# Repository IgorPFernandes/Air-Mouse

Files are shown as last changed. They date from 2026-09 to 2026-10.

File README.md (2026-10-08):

# Air Mouse

Mouse controlado por movimento da mão, feito com ESP32-C3 e MPU6050.

O aparelho se apresenta ao computador como um **mouse Bluetooth LE padrão (HID)**:
sem driver, sem dongle, sem software do lado do host. Funciona com Windows,
macOS, Linux, Android e iPadOS.

---

## Características

- **HID BLE nativo**, implementado direto sobre o NimBLE — sem biblioteca HID de
  terceiros.
- **Compensação de rotação do pulso** por filtro complementar: os eixos da tela
  continuam corretos mesmo com o aparelho inclinado de lado.
- **Curva de aceleração** com termo linear e quadrático: precisão no movimento
  fino, alcance no movimento rápido.
- **Acumulador de sub-pixel**, para que gestos lentos não sejam truncados a zero.
- **Calibração validada no boot** — a medição é rejeitada se o aparelho estiver
  sendo movido.
- **Modo scroll** com o botão do meio segurado.
- **Nível de bateria** reportado ao sistema operacional.
- **Gestão de energia em três estados** — ativo (~22 mA), ocioso com a conexão
  mantida (~1,9 mA) e sono profundo (~84 µA). Com duas 18650 em paralelo, cerca
  de **6,7 semanas** entre cargas numa jornada de 8 h com o aparelho na mão; ver
  [Autonomia](#autonomia).
- **Despertar por movimento**: pegar o aparelho já o acorda, sem apertar nada.
- **Botão de centralizar**, para reencontrar o cursor quando se perde de vista.
- **Três níveis de velocidade** com confirmação por LED RGB.

---

## Estrutura

```
├── include/
│   └── config.h              parâmetros de hardware e ajuste
├── src/
│   ├── main.cpp              inicialização e laço principal
│   ├── mpu6050.{h,cpp}       driver do sensor e calibração
│   ├── pointer.{h,cpp}       tratamento de sinal do cursor
│   ├── ble_mouse.{h,cpp}     perfil HID sobre BLE
│   ├── button.{h,cpp}        debounce
│   ├── recenter.{h,cpp}      centralizacao do cursor
│   ├── battery.{h,cpp}       leitura do ADC e curva da célula
│   ├── rgb_led.{h,cpp}       LED RGB: status e velocidade
│   └── power.{h,cpp}         clock, light sleep e sono profundo
├── tools/
│   └── i2c_scanner/          diagnóstico do barramento I²C
├── hardware/
│   └── caixa/                caixa imprimível da versão chaveiro (SCAD + STL)
└── docs/
```

---

## Documentação

| Documento | Conteúdo |
|---|---|
| [HARDWARE.md](docs/HARDWARE.md) | Lista de materiais, pinagem, alimentação e carga |
| [MONTAGEM.md](docs/MONTAGEM.md) | Montagem em etapas, com teste a cada uma |
| [ARQUITETURA.md](docs/ARQUITETURA.md) | Como o firmware funciona e por quê |
| [AJUSTES.md](docs/AJUSTES.md) | Ajuste de sensibilidade e diagnóstico |
| [ENERGIA.md](docs/ENERGIA.md) | Orçamento de consumo e autonomia |
| [CHAVEIRO_C6.md](docs/CHAVEIRO_C6.md) | Versão chaveiro com XIAO ESP32-C6, laser e controle IR (em projeto): lista de compras, ligações, botões |
| [hardware/caixa](hardware/caixa/README.md) | Caixa imprimível da versão chaveiro: STL, impressão e montagem |

---

## Início rápido

Ligações completas em [HARDWARE.md](docs/HARDWARE.md). O mínimo para funcionar:

| MPU6050 | ESP32-C3 |
|---|---|
| VCC | 3V3 |
| GND | GND |
| SDA | GPIO 5 |
| SCL | GPIO 6 |

### PlatformIO

```bash
pio run --target upload
```

### Arduino IDE

1. Instale o core **esp32 by Espressif**, versão 2.0.x.
2. Instale **NimBLE-Arduino** versão **1.4.x** (a 2.x mudou a API).
3. Copie `src/` e `include/config.h` para a pasta do sketch, renomeando
   `main.cpp` para o nome da pasta com extensão `.ino`.
4. Selecione **ESP32C3 Dev Module** com `USB CDC On Boot: Enabled`.

Se o upload falhar na SuperMini: segure **BOOT**, toque em **RESET**, solte o
**BOOT** e repita.

---

## Uso

1. Ligue e **deixe parado por cerca de 2 segundos** — o giroscópio é calibrado no
   boot. Movimento durante a calibração faz o cursor derivar depois.
2. Parear em *Bluetooth → Adicionar dispositivo → Air Mouse*.
3. LED apagado indica conexão estabelecida.

| Ação | Resultado |
|---|---|
| Girar a mão na horizontal | Move o cursor em X |
| Inclinar para cima e para baixo | Move o cursor em Y |
| Botão esquerdo | Clique esquerdo |
| Botão direito | Clique direito |
| Botão do meio segurado + movimento | Rolagem |
| Botão centralizar | Traz o cursor para perto do centro da tela |
| Botão velocidade | Percorre lento → médio → rápido |
| 4 s parado | Estado ocioso, conexão mantida |
| 20 min parado | Sono profundo |
| Mover o aparelho, ou botão esquerdo | Desperta |

O *bonding* está habilitado: depois do primeiro pareamento o host reconecta
sozinho.

| LED RGB | Estado |
|---|---|
| Azul fixo | Iniciando |
| Azul, piscada lenta | Anunciando, aguardando conexão |
| Vermelho, piscada rápida | MPU6050 não respondeu |
| Apagado | Conectado e em uso |
| Verde / amarelo / vermelho por 1,5 s | Velocidade rápida / média / lenta |

O LED não fica aceso mostrando a velocidade o tempo todo: um LED aceso consome
mais que o aparelho inteiro em repouso. A cor aparece na troca e ao conectar.

---

## Autonomia

> Todos os valores vêm de folhas de dados dos componentes. **Nada foi medido.**
> As correntes reais podem divergir; ver [como medir](docs/ENERGIA.md#medindo-de-verdade).

### Passo 1 — Capacidade realmente disponível

Partindo de duas células de 3400 mAh em paralelo:

| Etapa | Cálculo | Resultado |
|---|---:|---:|
| Nominal | 3400 × 2 | 6800 mAh |
| Término do TP4056 | −100 mAh | 6700 mAh |
| Corte por subtensão do circuito | × 0,92 | **6164 mAh** |

**O término do TP4056** custa pouco mesmo. Ele encerra quando a corrente cai a
~1/10 da programada — 100 mA com o ajuste de 1 A. Num pacote de 6800 mAh isso é
C/68, um ponto muito adiante na curva de tensão constante, então a célula termina
quase cheia. A perda fica entre 1% e 2%.

**O corte por subtensão é o fator que costuma passar despercebido.** A célula é
especificada até 2,5 V, e a proteção do módulo só atua por volta de 2,4 V — mas o
aparelho para de funcionar muito antes disso. O regulador de 3,3 V da placa perde
a regulação quando a entrada cai abaixo de ~3,5 V, e o ESP32-C3 começa a sofrer
brownout nos picos de transmissão do rádio.

Na curva de descarga de uma célula de lítio, o trecho de 4,2 V até ~3,4 V
concentra cerca de 92% da capacidade. Os 8% restantes existem na célula, mas
ficam abaixo da tensão em que este circuito ainda funciona. **São ~536 mAh
inacessíveis** — cinco vezes o que você descontou pelo TP4056.

### Passo 2 — Consumo de cada componente

#### Estado ativo — em movimento

| Componente | Corrente | Origem |
|---|---:|---|
| ESP32-C3, CPU a 80 MHz | ~11 mA | Modem-sleep com CPU ativa |
| Rádio BLE, intervalo 7,5 ms, latência 0 | ~7 mA | Média das janelas de RX/TX a 0 dBm |
| MPU6050, giroscópio + acelerômetro a 200 Hz | 3,8 mA | Folha de dados |
| Divisor de bateria (100 k + 100 k) | 0,019 mA | 3,8 V ÷ 200 kΩ |
| Regulador da placa (ME6211) | 0,040 mA | Corrente de repouso |
| LED RGB | 0 mA | Apagado quando conectado |
| **Total** | **~22 mA** | |

#### Estado ocioso — parado, conexão mantida

| Componente | Corrente | Origem |
|---|---:|---|
| ESP32-C3, light sleep + despertar a 50 Hz | ~1,2 mA | Ciclo de trabalho da CPU |
| Rádio BLE, slave latency 40 (~480 ms) | ~0,6 mA | Ciclo de trabalho de ~0,4% |
| MPU6050 em detecção de movimento a 5 Hz | 0,020 mA | Folha de dados, só acelerômetro |
| Divisor de bateria | 0,019 mA | |
| Regulador da placa | 0,040 mA | |
| **Total** | **~1,9 mA** | |

#### Sono profundo

| Componente | Corrente |
|---|---:|
| ESP32-C3 em sono profundo, despertar por GPIO | 0,005 mA |
| MPU6050 em detecção de movimento | 0,020 mA |
| Divisor de bateria | 0,019 mA |
| Regulador da placa (ME6211) | 0,040 mA |
| **Total** | **~0,084 mA** |

Repare que **o ESP32 é o menor consumidor aqui**. O regulador da placa sozinho
gasta oito vezes o que o microcontrolador gasta, e o divisor de bateria quatro
vezes. É por isso que trocar de placa muda mais o sono profundo do que qualquer
alteração de firmware.

### Passo 3 — Consumo por jornada

**O aparelho fica na mão, e isso muda tudo.** O estado ocioso exige 4 segundos
seguidos abaixo de 6 °/s. Uma mão humana segurando um objeto nunca fica assim:
tremor, balanço do corpo, gesticular ao falar, caminhar pela sala. O giroscópio
lê acima do limiar quase o tempo todo.

Na prática, **segurar o aparelho o mantém em estado ativo**. O estado ocioso só
entra em cena quando ele é apoiado em algum lugar.

Perfil de referência — 8 h na mão, 16 h desligado na chave:

| Fase | Duração | Corrente | Consumo |
|---|---:|---:|---:|
| Ativo | 8 h | 22 mA | 176 mAh |
| Desligado na chave | 16 h | 0 mA | 0 mAh |
| **Total por jornada** | | | **176 mAh** |

A chave física corta OUT+ antes do ESP32, então desligado é zero de verdade.
Deixar em sono profundo em vez de desligar custaria 1,3 mAh na noite — diferença
sem importância, mas a chave é o hábito mais simples de manter.

Dois perfis alternativos, para você situar o seu caso entre eles:

| Perfil | Ativo | Ocioso | Por jornada |
|---|---:|---:|---:|
| Na mão o tempo todo | 8 h | 0 h | 176 mAh |
| Na mão com pausas na mesa | 6 h | 2 h | 136 mAh |
| Apoiado, pego só para apontar | 0,8 h | 7,2 h | 33 mAh |

O primeiro é o realista para uso em sala de aula, e é o que orienta os números
adiante. Os outros dois exigem que o aparelho seja pousado com frequência.

### Passo 4 — A autodescarga, que ninguém conta

Uma célula de lítio perde de 2% a 5% da carga por mês, parada, sem estar ligada a
nada. Adotando 3%:

```
6164 mAh × 3% = 185 mAh por mês = 42,6 mAh por semana
```

Numa semana de trabalho, com o aparelho desligado nos fins de semana:

| Item | Por semana |
|---|---:|
| 5 jornadas × 176 mAh | 880 mAh |
| 2 dias de fim de semana, desligado | 0 mAh |
| Autodescarga | 43 mAh |
| **Total** | **923 mAh** |

A autodescarga não depende de uso — é a química da célula. Neste perfil ela
responde por 5% do total, mas num perfil leve chegaria a 20%, e é a razão pela
qual dobrar a capacidade rende menos que o dobro de autonomia.

### Resultado

```
6164 mAh ÷ 923 mAh por semana = 6,7 semanas
```

Com duas 18650 em paralelo:

| Perfil de uso | Autonomia |
|---|---|
| **Na mão o tempo todo (referência)** | **~6,7 semanas** (~1,5 mês) |
| Na mão com pausas na mesa | ~8,5 semanas |
| Apoiado, pego só para apontar | ~29 semanas |
| Movimento contínuo, sem parar | ~280 horas |

Comparação entre baterias, no perfil de referência:

| Bateria | Capacidade utilizável | Autonomia |
|---|---:|---|
| LiPo 1000 mAh | ~900 mAh | **~1 semana** |
| 1 × 18650 (3400 mAh) | ~3082 mAh | ~3,3 semanas |
| 2 × 18650 (6800 mAh) | ~6164 mAh | **~6,7 semanas** |

É aqui que as duas células se justificam. Com uma LiPo, o professor carregaria
toda semana; com uma 18650, a cada três semanas; com duas, a cada mês e meio. A
carga de 12 a 15 h passa a acontecer seis vezes por ano, num fim de semana.

### O que pode derrubar esses números

| Fator | Autonomia resultante |
|---|---|
| **Células falsificadas** | **~3,4 semanas.** Muita 18650 vendida como "3400 mAh" entrega 1500 a 2200 mAh reais |
| Regulador AMS1117 em vez de ME6211 | ~5,5 semanas (−18%) |
| LED de alimentação não removido | ~6,1 semanas (−9%) |
| Temperatura baixa | A 0 °C, espere 20 a 30% a menos de capacidade |
| Células desbalanceadas | 1 a 2% de perda |

**Atenção à mudança de ordem.** Num aparelho que fica ligado o tempo todo, o LED
de alimentação e o regulador dominam o consumo. Aqui não: com a chave desligada
16 h por dia e nos fins de semana, esses drenos só atuam durante as 8 h de uso, e
nelas os 22 mA do estado ativo já mandam em tudo.

Continua valendo desolder o LED e preferir uma placa com ME6211 — mas o fator
realmente perigoso passou a ser a **procedência das células**. Uma 18650 falsa
corta a autonomia pela metade, e esse é o erro mais comum e mais caro da lista.

### O que passou a valer a pena otimizar

O estado ativo virou praticamente todo o consumo, e ele se divide assim:

| Contribuição | Corrente | Fatia |
|---|---:|---:|
| ESP32-C3, CPU a 80 MHz | ~11 mA | 50% |
| Rádio BLE a 125 Hz | ~7 mA | 32% |
| MPU6050 a 200 Hz | 3,8 mA | 17% |

Toda a economia que o firmware faz hoje — light sleep, slave latency, giroscópio
em espera — atua sobre estados em que este aparelho quase não entra neste perfil
de uso. Se a autonomia precisar subir, os caminhos são outros: reduzir
`REPORT_HZ_ACTIVE` de 125 para 60 ou 75 Hz, e baixar a taxa do MPU6050 junto.
São mudanças que valem medir antes, porque mexem na resposta do cursor.

Discussão completa em [ENERGIA.md](docs/ENERGIA.md).

---

## Estado do projeto

O firmware está completo e documentado, mas **nunca foi compilado nem executado
em hardware**. A primeira compilação é o próximo passo.

Esta tabela existe para quem for montar: ela diz onde procurar primeiro quando
algo não funcionar.

| Subsistema | Estado | Risco |
|---|---|---|
| Driver do MPU6050 | Escrito | Baixo — registradores padrão, amplamente documentados |
| Pipeline do cursor | Escrito, matemática simulada | Baixo — a simulação confere as contas |
| HID BLE | Escrito, API conferida nos headers do NimBLE 1.4.3 | Médio — descritor e serviços não exercitados |
| Botões e debounce | Escrito | Baixo |
| Centralização do cursor | Escrito | Médio — depende da aceleração de ponteiro do sistema |
| Níveis de velocidade e RGB | Escrito | Baixo |
| Slave latency e parâmetros de conexão | Escrito | Médio — negociação pode ser recusada pelo host |
| Light sleep automático | Escrito, com detecção de ausência de suporte | Médio — depende do core ter power management |
| **Wake-on-motion do MPU6050** | **Escrito a partir da documentação** | **Alto — sequência de registradores não verificada** |
| Consumo e autonomia | Estimado por folha de dados | **Alto — nenhuma medição feita** |

Se algo falhar na bancada, comece pelas duas últimas linhas.

A [versão chaveiro](docs/CHAVEIRO_C6.md) está um passo atrás:

| Subsistema | Estado | Risco |
|---|---|---|
| Caixa do chaveiro | STL gerado e conferido no OpenSCAD, não impresso | Médio — medidas da bateria estimadas por foto |
| Firmware para o XIAO ESP32-C6 | Não iniciado | — exige core Arduino 3.x e nova pinagem |

Histórico completo do que foi construído em [CHANGELOG.md](CHANGELOG.md).

Relatos de erro de compilação ou de comportamento são bem-vindos via issue.

---

## Referências

O firmware foi escrito do zero, sem reaproveitamento de código. Estes projetos
foram consultados durante o desenvolvimento e valem a leitura:

| Projeto | Comentário |
|---|---|
| [k8r00/comet-air-mouse](https://github.com/k8r00/comet-air-mouse) | O mais próximo deste hardware (ESP32-C3 + MPU6050). A ideia do botão segurado como scroll veio dele. |
| [n1rml/esp32_airmouse](https://github.com/n1rml/esp32_airmouse) | Implementação em ESP-IDF, para o ESP32 clássico. |
| [WhoIsMrSentry/Esp32GestureMouse](https://github.com/WhoIsMrSentry/Esp32GestureMouse) | Boa referência de tratamento de botões. |
| [T-vK/ESP32-BLE-Mouse](https://github.com/T-vK/ESP32-BLE-Mouse) | A biblioteca clássica — **não funciona no C3**, depende de Bluetooth Classic ([issue #69](https://github.com/T-vK/ESP32-BLE-Mouse/issues/69)). |

Sobre a escolha de implementar o HID direto sobre o NimBLE em vez de usar uma
dessas bibliotecas, ver [ARQUITETURA.md](docs/ARQUITETURA.md).

---

## Licença

MIT — ver [LICENSE](LICENSE).

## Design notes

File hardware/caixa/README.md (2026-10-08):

# Caixa do chaveiro

Caixa imprimível da [versão chaveiro](../../docs/CHAVEIRO_C6.md): 40,4 × 37 ×
24,5 mm, com todas as quinas arredondadas, estrias nas laterais e um rasgo
discreto no canto traseiro de baixo para a argola do chaveiro.

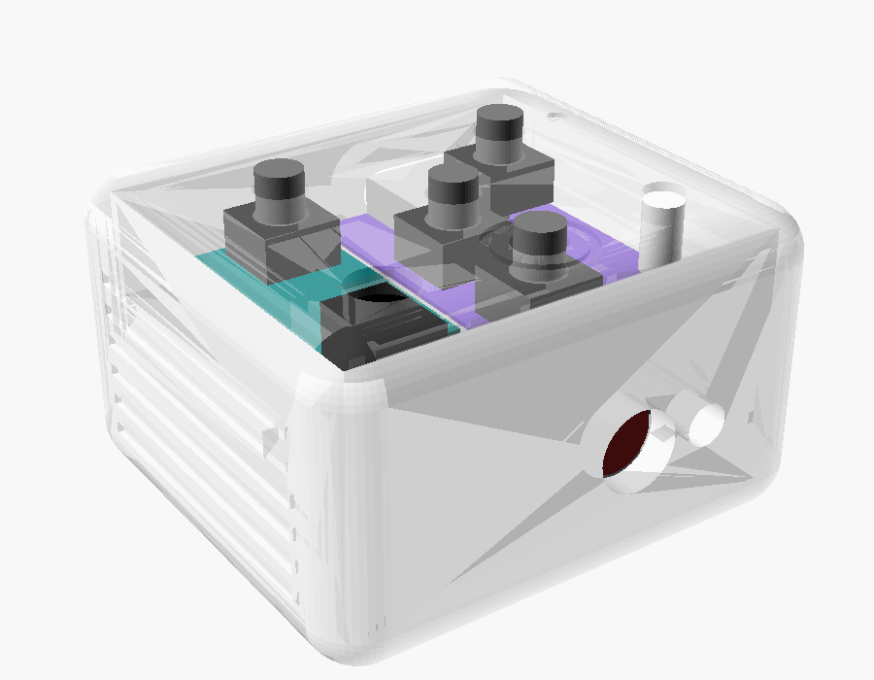
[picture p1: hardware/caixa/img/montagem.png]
Montagem


> Os STL foram gerados e conferidos no OpenSCAD (as três peças saem fechadas,
> sem erro), mas **nenhuma foi impressa ainda**. As medidas da bateria foram
> estimadas por foto — meça a sua antes de imprimir.

---

## Arquivos

| Arquivo | O que é |
|---|---|
| [air_mouse_case.scad](air_mouse_case.scad) | Modelo paramétrico (OpenSCAD) |
| [stl/air_mouse_base.stl](stl/air_mouse_base.stl) | Base: paredes, fundo, furos do laser e do LED IR, USB-C, rasgo da argola |
| [stl/air_mouse_tampa.stl](stl/air_mouse_tampa.stl) | Tampa: furos dos botões, janela do receptor IR, LED. Já vem virada para imprimir |
| [stl/air_mouse_bandeja.stl](stl/air_mouse_bandeja.stl) | Bandeja que segura o MPU6050 e a XIAO firmes, acima da bateria |

---

## Antes de imprimir: meça

Abra o `.scad` no [OpenSCAD](https://openscad.org) (gratuito) e ajuste no topo
do arquivo, na seção *Bateria com o TP4056 colado*:

| Parâmetro | Valor usado | O que medir |
|---|---|---|
| `bat_larg` | 30 mm | Largura da bateria |
| `bat_comp` | 30 mm | Comprimento, da ponta com a proteção até o lado do USB do TP4056 |
| `bat_esp` | 5,0 mm | Espessura, sem o TP4056 |
| `tp_larg` / `tp_comp` | 17,5 / 28 mm | Placa do TP4056 |
| `tp_recuo` | 0 mm | Quanto o USB do TP4056 fica para dentro da borda da bateria |
| `mpu_larg` / `mpu_comp` | 16 / 21 mm | Placa do GY-521, sem os pinos |

Depois de ajustar, escolha a peça em `peca` (base, tampa ou bandeja),
renderize com **F6** e exporte com **F7**. Pela linha de comando:

```bash
openscad -D 'peca="base"' -o air_mouse_base.stl air_mouse_case.scad
```

---

## Impressão

| Ajuste | Valor |
|---|---|
| Material | PETG (mais resistente a queda e calor) ou PLA |
| Altura de camada | 0,2 mm |
| Perímetros | 3 ou mais |
| Preenchimento | 20% |
| Suporte | **Nenhum** |

Orientação: a base com o fundo na mesa, a tampa com o topo na mesa (o STL já
sai assim) e a bandeja deitada. A barrinha da argola, o teto do bolsinho da
argola e o topo dos furos imprimem como ponte, sem suporte.

A tampa encaixa por pressão, com 0,15 mm de folga. Se ficar apertada, lixe a aba;
se ficar solta, um ponto de cola resolve.

---

## Onde vai cada coisa

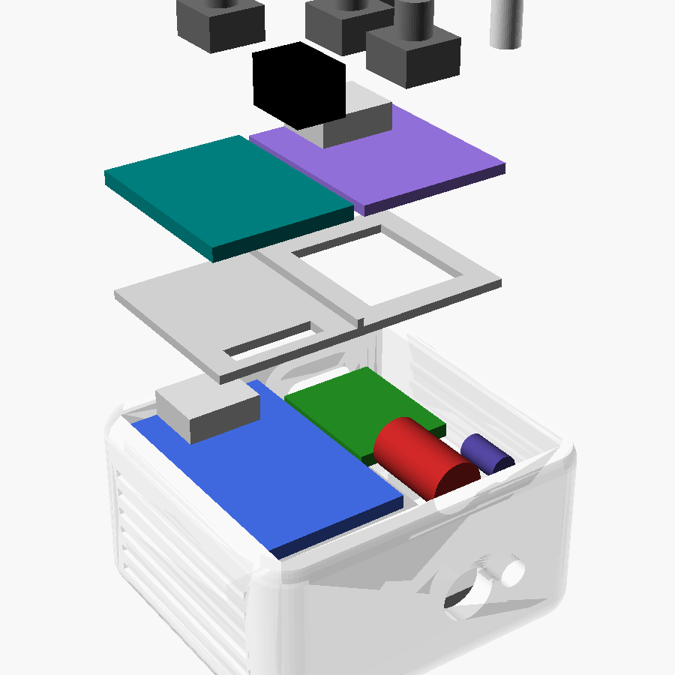
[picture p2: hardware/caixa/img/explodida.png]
Vista explodida


De baixo para cima:

1. **Bateria com o TP4056**, com o USB do TP4056 virado para trás. Isole com
   fita kapton.
2. **Laser e LED IR** deitados na faixa livre da bateria, ao lado do TP4056,
   apontando para os furos da frente. A plaquinha dos transistores fica logo
   atrás deles. Fixe com cola quente.
3. **Bandeja**, apoiada nos ressaltos das paredes. Cole nos ressaltos.
4. **MPU6050** (à esquerda) e **XIAO** (à direita) lado a lado na bandeja, com o
   USB-C da XIAO encostado no furo de trás. Cole o MPU firme. Os fios dos pads de
   baixo da XIAO passam pela janela da bandeja.
5. **Na tampa**: os 4 botões encaixados por baixo nos soquetes, o receptor IR
   deitado com a lente para cima e o LED RGB no furo da frente à direita.

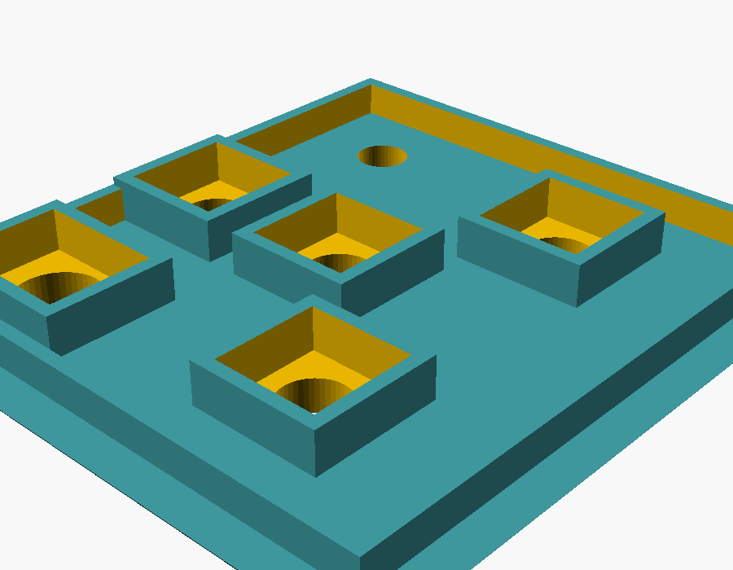
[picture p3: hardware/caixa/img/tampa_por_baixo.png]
Tampa por baixo


Monte e teste em etapas, como em [MONTAGEM.md](../../docs/MONTAGEM.md): ligue
o MPU e confira o cursor na bancada antes de colar qualquer coisa.

---

## Argola do chaveiro

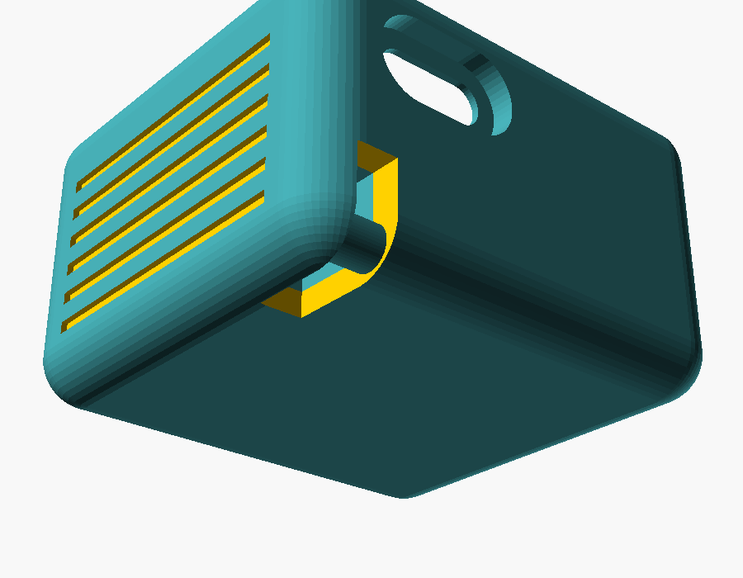
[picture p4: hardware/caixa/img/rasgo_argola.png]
Rasgo da argola


O rasgo de 3,4 mm no canto traseiro de baixo (lado direito) tem uma barrinha
escondida onde a argola abraça. Por dentro, um bolsinho fechado impede a argola
de encostar na bateria ou nos fios.

Pela simulação do caminho da argola, cabem argolas de até **25 mm com arame de
2 mm**, ou até **30 mm com arame de 1,5 mm**. Passe a argola girando, como se
coloca uma chave.

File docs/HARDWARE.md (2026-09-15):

# Hardware

## Lista de materiais

| Peça | Observação |
|---|---|
| ESP32-C3 | SuperMini ou DevKitM-1 |
| MPU6050 | Módulo GY-521 |
| 2 × 18650 3,7 V | Em **paralelo** — ver [Alimentação](#alimentação) |
| Suporte para 2 × 18650 | Ou solda direta em células com tab |
| Módulo de carga TP4056 | **Com proteção** (6 pinos, dois CIs) |
| 5 × botão táctil | Esquerdo, direito, meio, centralizar, velocidade |
| LED RGB de anodo comum | 5 mm ou SMD |
| 3 × resistor 220 Ω | Um por cor do RGB |
| Chave liga/desliga | Recomendada |
| 2 × resistor 100 kΩ | Divisor de bateria, opcional |
| 1 × capacitor 100 nF | Filtro do divisor, opcional |

---

## Pinagem

A SuperMini expõe treze GPIO. Doze estão em uso — o projeto está no limite.

| Sinal | Pino | Observação |
|---|---|---|
| MPU6050 SDA | GPIO 5 | I²C a 400 kHz |
| MPU6050 SCL | GPIO 6 | |
| MPU6050 INT | GPIO 0 | Desperta por movimento |
| MPU6050 VCC / GND | 3V3 / GND | O GY-521 aceita 3,3 V direto |
| Botão esquerdo | GPIO 3 | Também desperta do sono profundo |
| Botão direito | GPIO 4 | |
| Botão do meio | GPIO 10 | Segurado = modo scroll |
| **Botão centralizar** | **GPIO 7** | Leva o cursor ao centro da tela |
| **Botão velocidade** | **GPIO 9** | Percorre lento → médio → rápido |
| **RGB vermelho** | **GPIO 8** | Via resistor de 220 Ω |
| **RGB verde** | **GPIO 20** | Via resistor de 220 Ω |
| **RGB azul** | **GPIO 21** | Via resistor de 220 Ω |
| Divisor de bateria | GPIO 1 | ADC1 |
| *(livre)* | GPIO 2 | Deixado livre de propósito |

```
              ESP32-C3
            ┌───────────┐
   MPU6050  │           │
   VCC ─────┤ 3V3       │
   GND ─────┤ GND       │
   SDA ─────┤ GPIO 5    │
   SCL ─────┤ GPIO 6    │
   INT ─────┤ GPIO 0    │
            │           │
  Botão E ──┤ GPIO 3    │──┐
  Botão D ──┤ GPIO 4    │  │
  Botão M ──┤ GPIO 10   │  │ o outro lado de
  Centrar ──┤ GPIO 7    │  │ todos vai no GND
  Veloc.  ──┤ GPIO 9    │──┘
            │           │
  RGB R ─[220Ω]─ GPIO 8 │   anodo comum
  RGB G ─[220Ω]─ GPIO 20│   vai no 3V3
  RGB B ─[220Ω]─ GPIO 21│
            │           │
  Divisor ──┤ GPIO 1    │
   TP4056 ──┤ 5V        │
    OUT+    │           │
   TP4056 ──┤ GND       │
    OUT-    └───────────┘
```

Os botões usam o pull-up interno: um lado no GPIO, o outro no GND, sem resistor
externo.

### Pinos de strapping — leia antes de ligar

GPIO 2, 8 e 9 participam da escolha do modo de boot. Consequências práticas:

- **GPIO 9 é o pino BOOT.** Se o botão de velocidade estiver pressionado durante
  o reset, a placa entra em modo de gravação em vez de arrancar. É inofensivo, e
  na verdade conveniente na hora de gravar o firmware — só não estranhe.
- **GPIO 8 é seguro aqui porque o RGB é de ânodo comum.** Os pinos ficam em nível
  alto em repouso. Um RGB de *cátodo* comum inverteria isso e poderia atrapalhar
  o boot: não troque o tipo de LED sem trocar `RGB_COMMON_ANODE` e reavaliar.
- **GPIO 2 ficou livre** justamente por ser o mais sensível: em nível baixo no
  reset, a placa não arranca. Se precisar dele, garanta que nada o puxe ao GND.

GPIO 20 e 21 são a UART0, livres porque a serial de depuração usa o USB nativo.

---

## LED RGB

Uma peça, duas funções:

| Situação | Cor |
|---|---|
| Iniciando | Azul fixo |
| Anunciando, aguardando conexão | Azul, piscada lenta |
| MPU6050 não respondeu | Vermelho, piscada rápida |
| Conectado, em uso | **Apagado** |
| Velocidade rápida (ao trocar ou conectar) | Verde por 1,5 s |
| Velocidade média | Amarelo por 1,5 s |
| Velocidade lenta | Vermelho por 1,5 s |

O LED **não fica aceso** mostrando a velocidade o tempo todo, e isso é
deliberado: um LED aceso consome de 2 a 5 mA, mais que o aparelho inteiro em
repouso. Deixá-lo ligado anularia boa parte do trabalho de autonomia. A cor
aparece quando você troca a velocidade e quando o aparelho conecta — que são os
dois momentos em que você precisa da informação.

Para mudar a duração, ajuste `RGB_CONFIRM_MS`. Para deixá-lo permanentemente
aceso, o lugar é `rgb_led.cpp`, no caso `State::kConnected`.

---

## Botão de centralizar

Um mouse HID reporta **deslocamento relativo**, nunca posição absoluta: não
existe "vá para 960, 540". O firmware contorna isso em duas etapas: encosta o
cursor no canto superior esquerdo, onde o sistema operacional o prende, e de lá
caminha meia tela.

A primeira etapa é exata — por mais que se empurre, o cursor fica preso no
canto. A segunda não: a aceleração de ponteiro do sistema multiplica o
deslocamento conforme a velocidade, então a chegada é **próxima** do centro, não
exata. Para reencontrar um cursor perdido, é o suficiente.

Ajuste `SCREEN_WIDTH` e `SCREEN_HEIGHT` para a sua tela. Se a chegada ficar
sistematicamente longe do centro, aumente `RECENTER_STEPS`: passos menores e mais
espalhados sofrem menos com a aceleração.

No Windows, desmarcar "aumentar a precisão do ponteiro" torna a chegada quase
exata.

---

## Alimentação

### Duas 18650 em paralelo

```
   18650 #1  ──┬──(+)──┬── B+ ──┐
   18650 #2  ──┘       │        │  TP4056
                       │        │  (com proteção)
   18650 #1  ──┬──(−)──┴── B- ──┤
   18650 #2  ──┘                │
                     OUT+ ───[chave]─── 5V do ESP32-C3
                     OUT- ─────────────  GND do ESP32-C3
```

Em **paralelo**, não em série. A tensão continua 3,7 V nominais e a capacidade
soma: duas células de 3400 mAh dão 6800 mAh.

**O TP4056 carrega este pacote sem nenhum problema.** Ele é um carregador de um
estágio de tensão (1S) — o que significa um *nível de tensão*, não uma única
célula física. Para o TP4056, duas 18650 em paralelo são indistinguíveis de uma
18650 grande: mesmos 4,2 V de término, mesmo critério de encerramento.

O que ele **não** faz é carregar duas células em **série**. 2S resultaria em
8,4 V, exigiria um carregador e um BMS próprios, e essa tensão passaria do limite
do regulador da SuperMini.

### O que o paralelo compra, e o que não compra

O ganho é **capacidade**, não corrente. Uma única 18650 entrega de 2 a 10 A de
descarga contínua, e este aparelho consome 22 mA no pico — a capacidade de
corrente de uma célula já sobra por um fator de cem. O paralelo não deixa nada
mais rápido nem mais forte; ele dobra o tempo entre cargas, e só.

Vale ter isso claro antes de decidir, porque o peso extra está comprando dias de
autonomia, não desempenho.

### O pacote carrega completamente?

Sim, e por dois motivos que vale conhecer.

**Não há temporizador de segurança.** O TP4056 encerra por corrente, não por
tempo: termina quando a corrente cai a cerca de 1/10 da programada, durante a
fase de tensão constante. Uma carga de treze horas não é interrompida por nada.
Carregadores com temporizador de 6 a 8 h cortariam um pacote deste tamanho pela
metade; este não.

**E o pacote grande enche mais que um pequeno.** O corte é em corrente absoluta —
100 mA com o ajuste de 1 A. Num pacote de 400 mAh, 100 mA é C/4 e o corte
acontece cedo, com a célula em torno de 90%. Em 6800 mAh, 100 mA é **C/68**, e o
corte cai muito mais adiante na curva. Proporcionalmente, o pacote grande termina
mais cheio.

A corrente também se divide entre as células: 1 A em duas 18650 dá 0,5 A por
célula, cerca de 0,15C. Carga mansa, boa para a vida útil.

### O calor, que é o limite de verdade

O TP4056 é um regulador **linear**: ele dissipa a diferença de tensão em calor.
A 1 A, com a célula em 3,4 V, são `(5 − 3,4) × 1 = 1,6 W` num encapsulamento
SOP-8. A regulação térmica reduz a corrente ao aproximar-se de 145 °C no die, e o
sintoma é a carga demorar bem mais do que a conta sugere.

| Ajuste | Dissipação | Tempo real de carga |
|---|---|---|
| 1 A (padrão do módulo) | ~1,6 W, entra em limitação térmica | ~12 a 15 h |
| 500 mA (Rprog 2,4 kΩ) | ~0,8 W, sem limitação | ~14 h |

Baixar para 500 mA **quase não custa tempo**, porque a limitação térmica já
segurava a corrente de qualquer modo. Troca-se um módulo escaldando por um morno
pelo mesmo tempo total — e é a escolha certa se a carga acontecer com o aparelho
fechado na caixa.

Se catorze horas incomodarem, o caminho é o **TP5100**: ele é chaveado em vez de
linear, então não queima a diferença em calor e entrega 2 A sem esquentar como o
TP4056 esquenta a 1 A.

### Três cuidados com o paralelo

1. **Equalize antes da primeira ligação.** Células em paralelo com tensões
   diferentes trocam corrente entre si — a diferença de 0,5 V entre duas 18650
   pode gerar dezenas de ampères no instante da conexão. Carregue cada uma
   separadamente até a mesma tensão (meça com multímetro, diferença abaixo de
   0,05 V) antes de uni-las pela primeira vez.
2. **Use células iguais e do mesmo lote.** Mesma marca, mesmo modelo, idade
   parecida. Misturar células de capacidades ou resistências internas diferentes
   faz uma trabalhar mais que a outra.
3. **Prefira células sem proteção individual**, deixando a proteção por conta do
   TP4056. Dois circuitos de proteção em paralelo podem disparar de forma
   assimétrica e deixar uma célula carregando sozinha.

E o de sempre com 18650: elas entregam corrente de curto muito maior que uma
LiPo pequena. Um curto no circuito não é um fio que esquenta, é um fio que
derrete. Capriche na bitola e evite emendas frouxas dentro da caixa.

---

## O peso — vale conversar antes de comprar

Você supôs que as duas células não fariam "taaaaanta diferença". Os números
dizem o contrário:

| Peça | Peso |
|---|---|
| 18650 × 2 | ~92 g |
| Suporte das células | ~12 g |
| Caixa impressa dimensionada para elas | ~40 g |
| ESP32-C3 + MPU6050 + TP4056 | ~7 g |
| Botões, RGB, resistores, fios | ~8 g |
| **Total** | **~160 g** |

As células e o volume que elas obrigam são cerca de **90% do peso final**.

### Contra o que comparar

A tentação é comparar com um mouse de mesa, que pesa 100 a 140 g. **É a
comparação errada**: o mouse de mesa está apoiado na mesa, e a carga sustentada
pela mão é essencialmente zero — vence-se apenas o atrito. Este aparelho fica no
ar, e 100 g no ar se comparam a 0 g na mesa, não a 120 g na mesa.

A classe certa é a dos objetos que fazem o mesmo trabalho na mesma postura:

| Referência | Peso | Observação |
|---|---|---|
| Apresentador de slides comercial | 50 a 75 g | O objeto que este substitui |
| Controle de TV | 100 a 150 g | Usado em rajadas curtas, braço apoiado |
| Wii Remote com pilhas | 145 g | Fadiga documentada em sessões longas |

### Onde a massa está importa mais que quanta ela é

O gesto principal deste aparelho é girar o pulso, e o esforço para girar escala
com massa × distância ao quadrado. Duas consequências práticas:

- Com duas células, monte-as **lado a lado, nunca em fila**. Enfileiradas dão
  130 mm de comprimento e mais que dobram o esforço de rotação em relação às
  mesmas 160 g dispostas lado a lado em 65 mm.
- Em qualquer configuração, concentre a massa o mais perto possível do punho.
  Massa na ponta do aparelho é a pior posição possível para o gesto que este
  projeto pede o tempo todo.

E o retorno é menor do que parece, porque a autonomia já estava resolvida:

| Bateria | Autonomia | Peso do conjunto |
|---|---|---|
| LiPo 1000 mAh | ~1 semana | **~66 g** |
| 1 × 18650 (3400 mAh) | ~3,3 semanas | ~102 g |
| 2 × 18650 (6800 mAh) | ~6,7 semanas | ~160 g |

Jornada de 8 h com o aparelho na mão; cálculo no
[README](../README.md#autonomia).

**É neste perfil que as duas células se justificam.** Segurar o aparelho o mantém
em estado ativo — o estado ocioso só atua quando ele é apoiado — e o consumo sobe
para 176 mAh por jornada. Com uma LiPo, o professor carregaria toda semana; com
duas 18650, a cada mês e meio.

A troca continua sendo peso por autonomia, mas agora com números que mudam a
rotina de quem usa, e não apenas o número no papel.

A segunda célula troca **+58 g no punho por 3,4 semanas a mais entre cargas**.
Uma célula só usa exatamente a mesma ligação — é só omitir a segunda, sem mudar
nada no firmware.

A decisão depende de quanto tempo seguido o aparelho fica erguido. Se o professor
o segura durante a aula inteira, o peso vira queixa antes da autonomia virar
problema; se ele alterna entre segurar e apoiar, as duas células compensam. Vale
pegar uma 18650 na mão antes de fechar a caixa.

### Medição de bateria (opcional)

```
  OUT+ ──[100k]──┬──[100k]── GND
                 │
                 ├── GPIO 1
                 │
              [100nF]
                 │
                GND
```

O divisor voltou a ligar direto no GND: os 20 µA que ele drena são 0,3% de
6800 mAh em um ano, e o GPIO que fazia o chaveamento passou a ser o botão de
centralizar. Para retomar o chaveamento, defina `BATTERY_GATED 1` e escolha um
pino livre para `PIN_BAT_GND`.

Se o percentual sair pela metade ou dobrado, ajuste `BAT_DIVIDER_RATIO` — o valor
é `(R1 + R2) / R2`, ou seja, `2.0` com dois resistores iguais.

---

## Consumo e autonomia

Cálculo detalhado no [README](../README.md#autonomia): ~22 mA em uso, ~1,9 mA
parado com a conexão mantida e ~84 µA em sono profundo — este último supondo
regulador ME6211 e LED de alimentação removido.

### Duas modificações na placa que valem mais que o firmware

**Remova o LED de alimentação.** O LED vermelho que acende sozinho consome de 1 a
3 mA continuamente, inclusive com o ESP32 dormindo. A 2 mA são 48 mAh por dia —
mais que todo o resto do aparelho somado. Desolde o LED ou corte a trilha do
resistor em série.

**Confira o regulador.** Se a placa usar AMS1117, o repouso dele sozinho é de
~5 mA e o sono profundo deixa de significar qualquer coisa. ME6211 (~40 µA) e
XC6206 (~1 µA) servem.

Os números são brutais: um LED de 2 mA esquecido custa 336 mAh por semana e
derruba a autonomia de **29 para 11 semanas**. Um regulador AMS1117 a 5 mA
derruba para **4 semanas**. Nos dois casos, mais de dois terços da autonomia
jogados fora por componentes que não fazem nada de útil aqui.

---

## Montagem mecânica

O MPU6050 precisa estar **rigidamente preso** à caixa. Se o módulo se mover
dentro dela, o sensor lê essa vibração como movimento real e nenhum ajuste de
filtro resolve. Cola quente nas bordas do módulo basta.

Com duas 18650 lado a lado, a caixa fica com pelo menos 65 × 40 mm de seção.
Posicione as células o mais próximo possível do punho: massa concentrada longe da
mão aumenta muito o esforço para girar o aparelho, que é exatamente o gesto que
este projeto pede o tempo todo.

Deixe o conector USB do TP4056 acessível por uma abertura.

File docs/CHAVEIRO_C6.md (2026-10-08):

# Versão chaveiro (XIAO ESP32-C6)

> **Em projeto.** O firmware deste repositório ainda é o da versão ESP32-C3 com
> duas 18650. Este documento descreve a versão compacta, que já tem a caixa
> pronta para imprimir ([hardware/caixa](../hardware/caixa/README.md)). O
> firmware para o C6 é o próximo passo, e nada aqui foi montado ou medido.

Um air mouse do tamanho de um chaveiro, pensado para quem dá aula: aponta e clica
no computador, tem laser, e liga o projetor da sala com um código infravermelho
gravado do controle original — para nunca mais procurar o controle.

| | Versão C3 (atual) | Versão chaveiro |
|---|---|---|
| Placa | ESP32-C3 SuperMini | Seeed XIAO ESP32-C6 |
| Bateria | 2 × 18650 (6800 mAh) | LiPo 400 mAh com TP4056 colado |
| Caixa | ≥ 65 × 40 mm de seção, ~160 g | 40,4 × 37 × 24,5 mm |
| Extras | — | Laser, controle IR com gravação |

---

## Lista de compras

### Já tenho

| Peça | Observação |
|---|---|
| Seeed XIAO ESP32-C6 | Carregador de LiPo embutido, sono profundo de ~15 µA |
| MPU6050 (módulo GY-521) | Tirar os pinos e o LED de alimentação do módulo |
| LiPo ~400 mAh com TP4056 colado | Módulo USB-C **com proteção** (6 pads: IN, B+/B−, OUT+/OUT−) |

### Comprar

Modelos escolhidos para caber na caixa. Os três primeiros são os que mais
variam entre anúncios: confira os itens da coluna *Confira no anúncio*.

| Peça | Modelo | Pesquise por | Confira no anúncio | Qtd |
|---|---|---|---|---|
| Laser | Módulo laser de ponto 650 nm, **1 mW, 3 V, 6 × 10 mm**, com driver embutido | `650nm 1mW 3V 6x10mm laser dot module` (AliExpress, Amazon) | 1 mW (não 5 mW), 3 V (não 5 V), 6 mm de diâmetro, até 10,5 mm de comprimento, "dot" (ponto, não linha nem cruz) | 1 |
| LED infravermelho | **Vishay TSAL4400** — 3 mm, 940 nm, ±25°, 100 mA contínuo | `TSAL4400` (Mouser, DigiKey, LCSC, AliExpress) | 940 nm (não 850 nm), corpo de 3 mm | 1 |
| Receptor infravermelho | **Vishay TSOP38238** — 38 kHz, 2,5–5,5 V, 5 × 4,8 × 6,95 mm | `TSOP38238` | Componente solto de 3 pernas, não o módulo KY-022 na plaquinha | 1 |
| Botão táctil | Chave táctil 6 × 6 mm, **altura total 7 mm**, 4 terminais (ex.: BTT-A06-7.0, Metaltex série A06 de 7,0 mm) | `chave táctil 6x6x7mm` | Furo passante (não SMD), 7 mm com o atuador, corpo de 3,5 mm | 4 |
| LED RGB | LED RGB de 3 mm, **ânodo comum**, lente difusa, 4 terminais | `LED RGB 3mm ânodo comum difuso` | "Ânodo comum" (common anode) e 3 mm | 1 |
| Transistor | **SS8050** (onsemi ou JSMSEMI), NPN, TO-92, 1,5 A | `SS8050 TO-92` | SS8050, não S8050 — o S8050 aguenta só 0,5 A. Pinagem E-B-C | 2 |
| Capacitor | Eletrolítico 100 µF, 6,3 V ou 10 V, **5 × 5 mm** | `capacitor eletrolítico 100uF 6.3V 5x5` | Altura de 5 mm (os comuns têm 11 mm e não cabem) | 1 |
| Capacitor | Cerâmico 100 nF | `capacitor cerâmico 100nF` | — | 1 |
| Resistores | 1/8 W (menores que os de 1/4 W): 22 Ω, 2 × 68 Ω, 220 Ω, 2 × 1 kΩ, 2 × 100 kΩ, 2 × 200 kΩ | `resistor 1/8W` | — | 10 |
| Placa perfurada | Placa ilhada, cortada em ~11 × 15 mm para os transistores | `placa perfurada ilhada` | — | 1 |
| Fio | Wire wrap 30 AWG (isolamento Kynar) | `fio wire wrap 30AWG` | — | 1 rolo |
| Fita kapton | — | `fita kapton` | — | 1 |
| Argola de chaveiro | 25 mm, arame de até 2 mm | `argola chaveiro 25mm` | Ou até 30 mm se o arame for de 1,5 mm | 1 |
| Filamento | PETG (ou PLA) | — | PETG aguenta melhor queda e calor | — |

**Se não achar no Brasil:**

- **Laser:** quase todo anúncio daqui é de 5 V e 5 mW (o KY-008). Para sala de
  aula, vale importar o de 1 mW. O KY-008 com plaquinha nem cabe na caixa.
- **LED IR:** um `LED IR 940nm 3mm` genérico funciona, desde que seja de
  940 nm. O TSAL4400 tem a ficha conhecida (aguenta os pulsos de 120 mA do
  circuito).
- **Receptor:** o **VS1838B** é vendido em todo lugar e também serve. O soquete
  da tampa foi alargado para caber os dois.

---

## Ligações

O C6 só acorda do sono profundo pelos GPIO 0 a 7. A XIAO expõe três deles nas
laterais (D0–D2) e os outros quatro em **pads embaixo da placa** (MTMS, MTDI,
MTCK, MTDO). Os quatro botões e o INT do MPU precisam acordar a placa, então os
pads de baixo são obrigatórios — solde os fios neles antes de colocar a XIAO na
bandeja.

| Função | Pino da XIAO | GPIO | Ligação |
|---|---|---|---|
| Bateria (ADC) | D0 | 0 | BAT+ → 200 kΩ → D0 → 200 kΩ → GND, e 100 nF de D0 ao GND |
| Botão 2 · clique | D1 | 1 | Outro lado do botão no GND |
| Botão 4 · projetor | D2 | 2 | Outro lado no GND |
| Botão 1 · liga / laser | pad MTMS | 4 | Outro lado no GND |
| Botão 3 · centro | pad MTDI | 5 | Outro lado no GND |
| INT do MPU6050 | pad MTCK | 6 | |
| Sinal do receptor IR | pad MTDO | 7 | |
| SDA / SCL do MPU6050 | D4 / D5 | 22 / 23 | VCC do MPU no 3V3 |
| LED IR | D3 | 21 | Via transistor, ver abaixo |
| Laser | D9 | 20 | Via transistor, ver abaixo |
| Alimentação do receptor IR | D6 | 16 | O receptor só é ligado no modo de gravação (gasta ~1 mA) |
| LED RGB — R / G / B | D7 / D10 / D8 | 17 / 18 / 19 | R com 220 Ω, G e B com 68 Ω; ânodo comum no 3V3 |

Os botões usam o pull-up interno: não precisam de resistor. No LED RGB, verde e
azul levam resistor menor porque precisam de quase 3 V para acender e ficariam
apagados com 220 Ω no 3,3 V.

### Alimentação

```
LiPo ── TP4056 (B+/B−) ── OUT+ ──► pad BAT+ da XIAO
                          OUT− ──► pad BAT− da XIAO
```

Carregue pela **USB-C da XIAO**: ela carrega a bateria por dentro e é a mesma
porta usada para gravar o firmware. O TP4056 fica só como proteção da bateria.
Se quiser carregar pelo TP4056, ele vem de fábrica carregando a **1 A**, demais
para 400 mAh: troque o resistor marcado `122` (R3) por um de 3 kΩ (~400 mA) e
abra o furo dele na caixa (`abrir_usb_tp4056 = true`).

### Laser e LED IR

```
3V3 ──► laser (+)                 BAT+ ──► 22 Ω ──► LED IR (ânodo)
        laser (−) ──► coletor              LED IR (cátodo) ──► coletor
                      S8050                                    S8050
D9 ──► 1 kΩ ──► base                D3 ──► 1 kΩ ──► base
       100 kΩ da base ao GND               100 kΩ da base ao GND
        emissor ──► GND                     emissor ──► GND

100 µF entre BAT+ e GND, perto do LED IR
```

- O laser vai no **3V3**: o módulo de 3 V ligado direto na bateria (até 4,2 V)
  passaria da corrente.
- O LED IR vai no **BAT+**: os pulsos de ~120 mA puxados do 3V3 podem derrubar a
  tensão e reiniciar a placa. É essa corrente que dá alcance de controle remoto
  comum (8–10 m).

---

## Botões

| Botão | Toque | Dois toques | Segurar |
|---|---|---|---|
| 1 · liga / laser | Desligado: liga. Ligado: mostra a bateria no LED | Desliga | Laser aceso, cursor congelado |
| 2 · clique | Clique esquerdo (avança o slide no PowerPoint) | Duplo clique normal | Arrastar |
| 3 · centro | Centraliza o cursor | Troca a velocidade (lento → médio → rápido) | Inclinar para rolar a tela |
| 4 · projetor | Envia o código IR gravado | Envia o 2º código | 3 s: grava um código novo |
| 3 + 4 juntos | — | — | 5 s: parear um PC novo |

O laser só acende depois de ~150 ms segurando: assim os toques para ligar e
desligar não fazem o laser piscar.

### Gravar o código do projetor

1. Segure o botão 4 por 3 s — o LED pisca, avisando que está gravando.
2. Aponte o controle do projetor para o **topo** do chaveiro, a uns 5 cm, e
   aperte Power uma vez.
3. LED verde: o código foi salvo na flash (sobrevive ao sono e à bateria
   acabando). LED vermelho: nada chegou em 10 s.

Para usar, toque no botão 4 apontando para o projetor. Muitos projetores pedem
dois toques em Power para desligar.

---

## Energia

| Estado | Como entra | Como sai | Consumo estimado |
|---|---|---|---|
| Desligado | Dois toques no botão 1, ou 3 min sem PC conectado | Toque no botão 1 | ~30 µA |
| Ativo | Ao ligar, movimento ou qualquer botão | Parado por 4 s | ~22 mA |
| Ocioso | Parado por 4 s, conexão mantida | Movimento | ~1,9 mA |
| Dormindo | Parado por 20 min | Movimento ou botão | ~50 µA |

- **Desligado não acorda com movimento**, só com o botão 1. É o estado para
  levar na bolsa.
- **Desliga sozinho** depois de 3 min sem PC conectado. Usar o laser ou o IR
  reinicia a contagem, para dar para ligar o projetor antes do computador.
- Os consumos de ativo e ocioso são as estimativas do C3 em
  [ENERGIA.md](ENERGIA.md). Nada foi medido no C6.

Com 400 mAh: ~2 dias com 8 h por dia na mão, ~5 dias numa rotina de aula
(~3 h de uso ativo por dia), e mais de um ano guardado desligado.

---

## Cuidados

- **Laser**: 1 mW no máximo. Nunca apontar para o rosto de ninguém.
- **MPU6050 firme**: cole o módulo na bandeja. Se ele balançar dentro da caixa,
  o cursor treme.
- **LED do GY-521**: tire o LED de alimentação do módulo — ele gasta o tempo
  todo, inclusive em sono profundo.
- **PC da sala**: muito desktop de escola não tem Bluetooth, ou tem o pareamento
  bloqueado pela TI. Um adaptador USB Bluetooth resolve o primeiro caso.

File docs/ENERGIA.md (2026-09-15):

# Energia e autonomia

> Os números abaixo são **estimativas de projeto**, calculadas a partir das
> folhas de dados e do comportamento esperado do rádio. Nada foi medido com
> multímetro ainda. Ver [Medindo de verdade](#medindo-de-verdade).

---

## Os três estados

| Estado | Quando | Consumo estimado | Custo para sair |
|---|---|---|---|
| **Ativo** | Em movimento ou com botão pressionado | ~22 mA | — |
| **Ocioso** | 4 s parado, conexão mantida | ~1,9 mA | ~50 ms |
| **Sono profundo** | 20 min parado | ~84 µA | 1 a 2 s (reconexão) |

A composição de cada valor, peça por peça, está no
[README](../README.md#passo-2--consumo-de-cada-componente). Os 84 µA supõem um
regulador ME6211 na placa e o LED de alimentação removido; sem essas duas
condições o número muda de ordem de grandeza.

O estado **ocioso** é o que faz a diferença no uso real. Um mouse passa a maior
parte do tempo parado entre um gesto e outro, e sair dele custa 50 ms — na
prática, imperceptível. Sem esse estado intermediário haveria só a escolha ruim
entre ficar em 22 mA o tempo todo ou pagar reconexão a cada pausa.

---

## O que mudou em relação à primeira versão

| Medida | Antes | Depois | Economia |
|---|---|---|---|
| Frequência de CPU | 160 MHz | 80 MHz | ~8 mA no estado ativo |
| Potência de transmissão | +9 dBm | 0 dBm | Corrente de pico nas rajadas |
| Espera entre quadros | Laço girando | `delay()` com light sleep | Grande, depende do suporte a PM |
| Slave latency em repouso | 0 | 40 | Rádio acorda a cada ~480 ms em vez de 7,5 ms |
| Giroscópio em repouso | Sempre ligado, 3,9 mA | Em espera, ~20 µA | 3,9 mA |
| Divisor de bateria | 20 µA contínuos | 20 µA — ver nota | — |
| Anúncio sem conexão | Rápido para sempre | Lento após 30 s, dorme após 3 min | Evita drenar a bateria esquecido |
| Despertar | Só botão | Botão **ou** movimento | Usabilidade, não consumo |

### O que é *slave latency*, e por que importa tanto

Num BLE HID, o intervalo de conexão precisa ser curto (7,5 ms) para o cursor
responder sem atraso. Mas manter 7,5 ms significa o rádio acordar 133 vezes por
segundo, mesmo com o aparelho parado na mesa.

*Slave latency* resolve isso: com latência 40, o periférico tem permissão de
ignorar até 40 eventos consecutivos quando **não tem nada a enviar**. O host
continua acreditando num intervalo de 7,5 ms e, no instante em que há
movimento, o relatório sai no evento seguinte — sem renegociar nada.

É exatamente o mecanismo que mouses e teclados BLE comerciais usam. O firmware
alterna entre latência 0 (ativo) e 40 (ocioso) nas transições de estado.

### Nota sobre o divisor de bateria

O chaveamento do divisor chegou a existir, mas foi revertido: o GPIO que o fazia
passou a ser o botão de centralizar, quando os controles novos esgotaram os pinos.
Os 20 µA que o divisor drena são 0,3% de uma 18650 em um ano — irrelevantes nesta
escala de bateria, ainda que fossem significativos com uma LiPo de 400 mAh.

Para retomar o chaveamento, defina `BATTERY_GATED 1` e escolha um pino livre para
`PIN_BAT_GND`. Só o GPIO 2 está livre, e ele é pino de strapping.

---

## Autonomia

O cálculo detalhado, componente por componente, está no
**[README](../README.md#autonomia)** — capacidade realmente disponível, consumo
de cada peça em cada estado, consumo por jornada e autodescarga.

Resumo, com duas 18650 em paralelo e uma jornada de 8 h com o aparelho na mão:
**~6,7 semanas** entre cargas.

Três pontos que o cálculo deixa claros e que vale destacar aqui:

**Segurar o aparelho o mantém em estado ativo.** O estado ocioso exige 4 s
seguidos abaixo de 6 °/s, e uma mão humana segurando um objeto nunca fica assim.
O estado ocioso só entra em cena quando o aparelho é apoiado. Isso significa que,
em uso de sala de aula, a economia do estado ocioso quase não é exercida — e o
consumo do estado ativo passa a ser praticamente o consumo total.

**Nem toda a capacidade é acessível.** O aparelho para de funcionar quando a
célula chega perto de 3,4 V, porque o regulador da placa perde a regulação e o
ESP32-C3 sofre brownout nos picos do rádio. Os ~8% de capacidade que existem
abaixo disso são inalcançáveis — cerca de 536 mAh num pacote de 6800 mAh.

**A autodescarga responde por 20% do consumo.** Uma célula de lítio perde de 2% a
5% ao mês parada, independentemente de uso. Em prazos de meses isso deixa de ser
detalhe: é a razão de dobrar a capacidade render menos que o dobro de autonomia.
Ver a discussão de peso em
[HARDWARE.md](HARDWARE.md#o-peso--vale-conversar-antes-de-comprar).

---

## Por que o sono profundo demora 20 minutos

`IDLE_SLEEP_MS` é 20 min, não 2. Sair do sono profundo custa uma reconexão BLE de
1 a 2 s, que no meio de uma aula aparece como um aparelho que não responde quando
se aponta para a tela.

O estado ocioso custa 2 mA. Uma jornada inteira de 8 h sem dormir nenhuma vez
gasta 16 mAh — meio por cento de uma 18650. Trocar isso por latência diante de
uma turma não se justifica.

Para um aparelho de uso doméstico esporádico, valores entre 2 e 5 min fazem mais
sentido.

---

## Os dois limites que o firmware não alcança

Aqui está a parte desconfortável: **o hardware da placa pode inviabilizar tudo
acima**, e nenhuma linha de código conserta isso.

### 1. O LED de alimentação da placa

Quase toda placa de desenvolvimento tem um LED vermelho que acende assim que há
tensão e nunca apaga. Ele consome de 1 a 3 mA **o tempo todo**, inclusive com o
ESP32 em sono profundo.

A 2 mA contínuos, são 48 mAh por dia — praticamente o dobro de tudo o que o
firmware gasta no perfil realista. Um aparelho que dorme a 65 µA com um LED de
2 mA ao lado está, na prática, consumindo 2 mA.

**A solução é remover o LED**: desolde-o, ou corte a trilha do resistor em série
com um estilete. É a modificação de maior retorno do projeto inteiro.

### 2. O regulador de tensão

O consumo em repouso do regulador de 3,3 V da placa aparece direto no total:

| Regulador | Corrente de repouso | Efeito no sono profundo |
|---|---|---|
| ME6211 | ~40 µA | Aceitável |
| XC6206 | ~1 µA | Excelente |
| **AMS1117** | **~5 mA** | **Destrói qualquer economia** |

O AMS1117 é comum em placas baratas e consome sozinho mais do que o resto do
aparelho somado. Se a sua SuperMini tiver um, o sono profundo não serve para
nada: 5 mA contínuos são 120 mAh por dia.

Identifique o CI regulador da sua placa antes de contar com os números deste
documento. Trocar de placa é mais simples do que trocar o regulador.

---

## Medindo de verdade

As estimativas acima valem pouco sem confirmação. Para medir:

1. Desligue a serial: `#define DEBUG_SERIAL 0`. O USB CDC mantém circuitos
   ativos e mascara completamente o consumo em repouso.
2. Alimente pela bateria, não pelo USB.
3. Meça em série com o positivo da bateria.

Um multímetro comum **não serve** para o sono profundo: a faixa de µA costuma
ter resistência interna alta o bastante para derrubar a tensão, e a comutação
entre faixas perde as rajadas do rádio. Para os estados ativo e ocioso ele
serve; para o sono profundo é preciso um medidor dedicado.

Ordem sugerida: meça primeiro o sono profundo. Se der muito acima de 300 µA,
o problema está no LED ou no regulador, e otimizar firmware não vai adiantar.

---

## Ajustando o compromisso

Todos os parâmetros estão em [`include/config.h`](../include/config.h).

| Quero | Ajuste |
|---|---|
| Mais autonomia, aceitando pausa perceptível | Reduza `IDLE_ENTER_MS` para `2000` |
| Menos espera ao voltar a usar | Aumente `IDLE_ENTER_MS`, ou `IDLE_SLEEP_MS` para adiar a reconexão |
| Ainda mais economia em repouso | Aumente `CONN_LATENCY_IDLE` para `60` — respeite `CONN_TIMEOUT` |
| Mais alcance | Aumente `BLE_TX_POWER_DBM` para `3` ou `6` |
| Cursor mais responsivo, custe o que custar | `REPORT_HZ_ACTIVE 200`, `CONN_LATENCY_IDLE 0` |
| Não montei o pino INT | `WAKE_ON_MOTION_ENABLED 0` — volta a despertar só por botão |

`CONN_TIMEOUT` precisa ser maior que `intervalo × (latency + 1)`. Com intervalo
de 15 ms e latência 40, são 615 ms; o padrão de 6 s dá folga larga. Latências
muito altas com timeout curto derrubam a conexão de forma intermitente e difícil
de diagnosticar.

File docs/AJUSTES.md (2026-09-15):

# Ajuste do comportamento

Todos os parâmetros ficam em [`include/config.h`](../include/config.h). O efeito
de cada um está descrito em [ARQUITETURA.md](ARQUITETURA.md).

Para ver os números ao vivo enquanto ajusta, defina `DEBUG_PLOT_MS 100` e abra o
monitor serial.

---

## Diagnóstico rápido

| Sintoma | Ajuste |
|---|---|
| Cursor anda no sentido contrário | Alterne `INVERT_X` ou `INVERT_Y` entre `0` e `1` |
| Horizontal e vertical trocados | `SWAP_AXES 1` |
| Cursor treme com o aparelho parado | Aumente `GYRO_DEADZONE_DPS` para `2.0` ou `2.5` |
| Cursor deriva sozinho, sempre no mesmo sentido | Reinicie com o aparelho imóvel: a calibração pegou movimento |
| Cursor lento para atravessar a tela | Aumente `ACCEL_GAIN` (`0.0016` → `0.003`) |
| Difícil acertar alvos pequenos | Reduza `SENSITIVITY` e `ACCEL_GAIN` |
| Cursor "molhado", com atraso | Reduza `SMOOTHING` (`0.35` → `0.2`) |
| Movimento picotado em gestos lentos | Reduza `GYRO_DEADZONE_DPS` |
| Scroll rápido demais | Aumente `SCROLL_DIVISOR` |
| Scroll no sentido errado | `SCROLL_INVERT 1` |
| Cursor anda na diagonal com o aparelho inclinado | Confirme `ROLL_COMPENSATION 1` |
| Centralizar não chega no centro | Confira `SCREEN_WIDTH` e `SCREEN_HEIGHT`; aumente `RECENTER_STEPS` |
| Centralizar erra sempre para o mesmo lado | É a aceleração de ponteiro do sistema; no Windows, desmarque "aumentar a precisão do ponteiro" |
| RGB com as cores trocadas | Confira a ordem dos pinos; um LED de cátodo comum precisa de `RGB_COMMON_ANODE 0` |
| Cor da velocidade some rápido demais | Aumente `RGB_CONFIRM_MS` |

---

## Níveis de velocidade

O botão de velocidade percorre três níveis, e a cor do RGB confirma qual está
valendo por 1,5 s. O multiplicador incide sobre `SENSITIVITY` e `ACCEL_GAIN` ao
mesmo tempo, então a curva mantém o formato e só muda de escala.

```c
#define SPEED_SLOW_SCALE   0.55f   // vermelho
#define SPEED_MEDIUM_SCALE 1.00f   // amarelo — os valores abaixo como estão
#define SPEED_FAST_SCALE   1.60f   // verde
#define SPEED_DEFAULT      1       // 0 lento, 1 médio, 2 rápido
```

Ajuste primeiro os parâmetros base no nível médio, que é o de escala 1,0. Os
outros dois são derivados dele — mexer na base move os três de uma vez, que é o
comportamento desejado.

O nível escolhido fica na RAM do RTC e sobrevive ao sono profundo, mas não a
desligar a chave. `SPEED_DEFAULT` é o nível ao ligar do zero.

---

## Os dois parâmetros principais

```c
#define SENSITIVITY 0.085f  // ganho linear: velocidade geral
#define SMOOTHING   0.35f   // suavização: estabilidade contra latência
```

Ajuste `SENSITIVITY` primeiro, até a velocidade geral ficar confortável. Só então
mexa em `SMOOTHING`, e em passos pequenos: é o parâmetro que troca estabilidade
por latência, e valores acima de `0.6` deixam o cursor perceptivelmente atrasado
em relação à mão.

`ACCEL_GAIN` é o que separa "preciso" de "rápido". Se você quer os dois, aumente
`ACCEL_GAIN` e reduza `SENSITIVITY` — movimento lento fica fino, movimento rápido
continua cobrindo a tela.

---

## Ordem recomendada

1. **Eixos.** `INVERT_X`, `INVERT_Y`, `SWAP_AXES`. Faça com o aparelho ainda na
   bancada, antes de fechar a caixa.
2. **Zona morta.** Aponte para um alvo e solte a mão: o cursor deve ficar imóvel.
   Aumente `GYRO_DEADZONE_DPS` até parar de tremer, sem passar disso — cada
   décimo a mais tira resolução do movimento fino.
3. **Velocidade.** `SENSITIVITY`, depois `ACCEL_GAIN`.
4. **Suavização.** `SMOOTHING`, por último e em passos pequenos.
5. **Scroll.** `SCROLL_DIVISOR` e `SCROLL_INVERT`.

---

## Energia

```c
#define IDLE_SLEEP_MS   (5UL * 60UL * 1000UL)  // tempo até dormir
#define IDLE_MOTION_DPS 6.0f                   // acima disso conta como uso
```

Se o aparelho dormir enquanto está em uso, reduza `IDLE_MOTION_DPS`. Se nunca
dormir, o valor está baixo demais e o ruído do sensor está sendo lido como
atividade.

Lembre que despertar é um reset: o giroscópio é recalibrado, então o aparelho
precisa estar parado no momento em que acorda.

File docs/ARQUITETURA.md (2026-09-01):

# Arquitetura do firmware

Este documento descreve como o firmware está organizado e, principalmente,
**por que** o tratamento do sinal é feito nessa ordem. A parte difícil de um air
mouse não é ler o sensor — é transformar velocidade angular em um cursor que se
comporte bem.

---

## Visão geral

```
   MPU6050 ──I²C──▶ mpu6050 ──ImuSample──▶ pointer ──PointerOutput──▶ ble_mouse ──BLE──▶ host
                                              ▲
                                              │
                        button ───────────────┘  (modo scroll)

   battery ──▶ ble_mouse (nível de bateria)
   status_led, power  ◀── main
```

`main.cpp` não contém regra de negócio: inicializa os módulos, mantém a cadência
fixa e decide quando enviar relatório ou dormir.

| Módulo | Responsabilidade |
|---|---|
| `mpu6050` | Acesso I²C ao sensor, calibração e remoção de bias |
| `pointer` | Todo o tratamento de sinal: filtros, curva, sub-pixel, scroll |
| `ble_mouse` | Perfil HID sobre BLE e envio dos relatórios |
| `button` | Debounce de um botão em pull-up |
| `battery` | Leitura do ADC e conversão para percentual |
| `status_led` | Estado visual do aparelho |
| `power` | Sono profundo e despertar |
| `config.h` | Único ponto de configuração |

Cada módulo é um namespace com estado interno em anônimo — não há singleton nem
alocação dinâmica fora do NimBLE, que exige.

---

## O pipeline de movimento

Tudo acontece em `pointer.cpp`, na função `update()`. A ordem importa: trocar
duas etapas de lugar degrada o resultado de forma visível.

### 1. Remoção de bias (em `mpu6050`)

Todo giroscópio MEMS tem um desvio de zero — parado, ele reporta algo diferente
de zero. Uns poucos graus por segundo bastam para o cursor atravessar a tela
sozinho em alguns segundos.

O bias é medido no boot, com a média de 600 amostras. A medição **se valida**:
se a variação entre a menor e a maior leitura passar de 25 deg/s, a placa estava
sendo movida, a média não representa o desvio de zero, e `calibrate()` retorna
`false`. `main` tenta até três vezes.

Essa validação é o que evita o modo de falha mais comum e mais confuso do
projeto: calibrar com o aparelho na mão e não entender por que o cursor deriva.

### 2. Compensação de rotação do pulso

O giroscópio mede rotação nos eixos **dele**, não nos da tela. Se o usuário
segura o aparelho inclinado 30°, girar o pulso na horizontal produz componente
nos dois eixos e o cursor anda na diagonal.

A correção usa um filtro complementar:

```
roll = 0.98 * (roll + gx * dt) + 0.02 * atan2(ay, az)
```

O giroscópio dá a variação rápida e precisa do ângulo, mas acumula deriva; o
acelerômetro sabe onde é "para baixo" pela gravidade, mas é ruidoso sob
movimento. O peso 0.98/0.02 confia no giroscópio no curto prazo e deixa a
gravidade corrigir a deriva lentamente.

Com o ângulo em mãos, o vetor de movimento é rotacionado de volta para os eixos
da tela. Desligável em `ROLL_COMPENSATION`.

### 3. Zona morta subtrativa

O tremor natural da mão fica na casa de 1 a 2 deg/s. Sem filtro, o cursor vibra
parado.

O detalhe está em **subtrair** o limiar em vez de zerar abaixo dele:

```c
if (v >  limiar) return v - limiar;
if (v < -limiar) return v + limiar;
return 0;
```

Zerar cria um degrau — ao cruzar a borda, o cursor salta de parado para a
velocidade cheia. Subtraindo, a saída cresce a partir do zero e o movimento
começa suave.

### 4. Suavização exponencial

Média móvel de um polo, com peso em `SMOOTHING`. Tira o ruído que sobrou. Custa
latência: quanto maior o valor, mais suave e mais "molhado" fica o cursor.

### 5. Curva de aceleração

```
saída = |v| * SENSITIVITY + |v|² * ACCEL_GAIN
```

O termo linear domina no movimento lento e dá precisão para acertar um botão. O
termo quadrático domina no movimento rápido e permite atravessar a tela com um
giro curto de pulso. É o mesmo princípio da aceleração de ponteiro do sistema
operacional.

### 6. Acumulador de sub-pixel

O relatório HID carrega inteiros. Um movimento lento que produza 0,4 px por
quadro seria truncado para 0 — e a 125 Hz isso significa cursor **totalmente
parado** em movimentos finos, justamente onde a precisão importa.

A fração é guardada entre quadros:

```c
residual += curva(v);
passo = trunc(residual);
residual -= passo;
```

Assim os 0,4 px viram 1 px a cada dois quadros e meio, em vez de nada.

---

## Cadência e envio

O laço roda a `REPORT_HZ` (125 Hz por padrão) com `dt` constante. Manter o `dt`
estável importa porque tanto o filtro complementar quanto a suavização assumem
intervalo regular; um `dt` que varia com o tempo gasto no rádio faria a resposta
do cursor variar junto.

O relatório só é enviado quando há deslocamento, roda ou mudança de botão.
Relatórios de zero repetidos não informam nada ao host e gastam rádio.

---

## Energia

Após `IDLE_SLEEP_MS` sem movimento acima de `IDLE_MOTION_DPS` e sem botão, o
aparelho entra em sono profundo. O MPU6050 também é posto para dormir antes.

O despertar é por nível baixo no botão esquerdo. **No ESP32-C3 apenas os
GPIO 0 a 5 acordam o chip do sono profundo** — a restrição é verificada em tempo
de compilação por um `static_assert` em `power.cpp`, para que mudar o pino no
`config.h` para um valor inválido falhe na compilação em vez de produzir um
aparelho que nunca acorda.

Despertar do sono profundo é um reset: `setup()` roda de novo e o giroscópio é
recalibrado.

---

## Por que HID direto sobre o NimBLE

O ESP32-C3 tem **apenas BLE**, sem Bluetooth Classic. As bibliotecas de mouse
mais citadas para ESP32 dependem do Bluedroid com Bluetooth Classic e não
funcionam nesta peça.

As alternativas em BLE são bibliotecas de terceiros que encapsulam o NimBLE e
tendem a quebrar a cada atualização do core do Arduino. Como o NimBLE já traz
`NimBLEHIDDevice` com tudo o que é preciso, a camada extra só adicionaria
superfície de falha. `ble_mouse.cpp` inteiro tem menos de 150 linhas.

Um detalhe não óbvio, marcado no código: a sobrecarga `manufacturer(std::string)`
é usada de propósito. Passar um `const char*` para `setValue()` casa com o
template genérico do NimBLE e grava o **ponteiro**, não o texto.

---

## Descritor HID

Mouse padrão de 5 botões, com uma escolha deliberada: X e Y em **16 bits** em vez
dos 8 bits do descritor clássico. Em 8 bits o deslocamento satura em 127 por
relatório, e movimentos rápidos ficam truncados — o cursor parece engasgar
justamente quando se gira a mão depressa.

Campos: botões (5 bits + 3 de preenchimento), X (int16), Y (int16), roda (int8),
AC Pan (int8). Sete bytes, com o Report ID transportado fora pelo NimBLE.

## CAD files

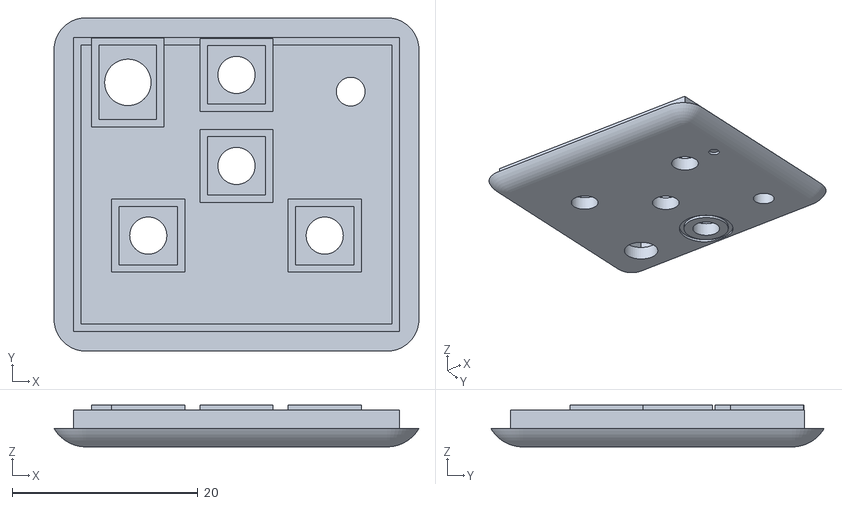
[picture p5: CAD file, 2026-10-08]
hardware/caixa/stl/air_mouse_tampa.stl
39.3 x 35.9 x 4.49

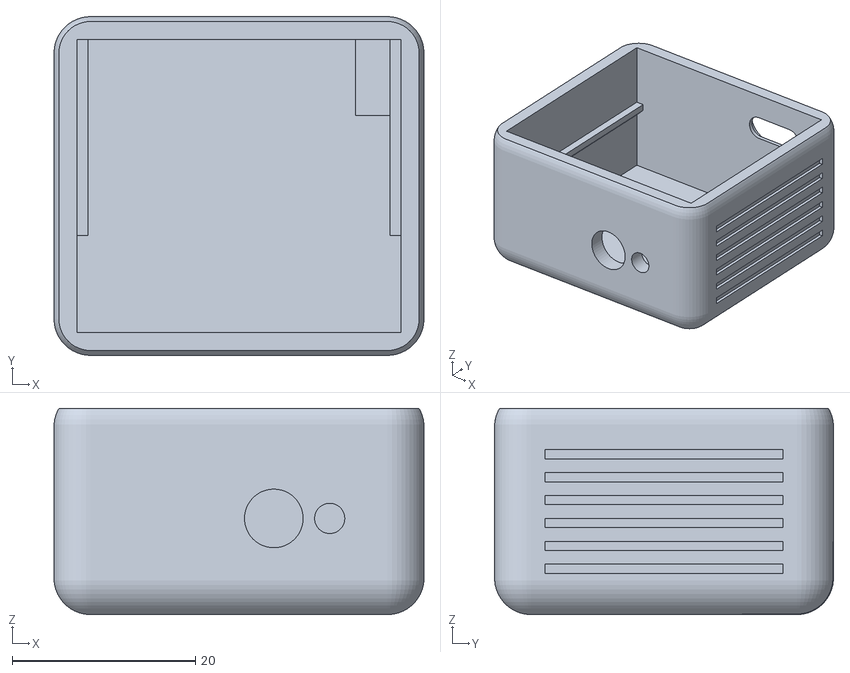
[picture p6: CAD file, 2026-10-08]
hardware/caixa/stl/air_mouse_base.stl
40.4 x 37.0 x 22.5

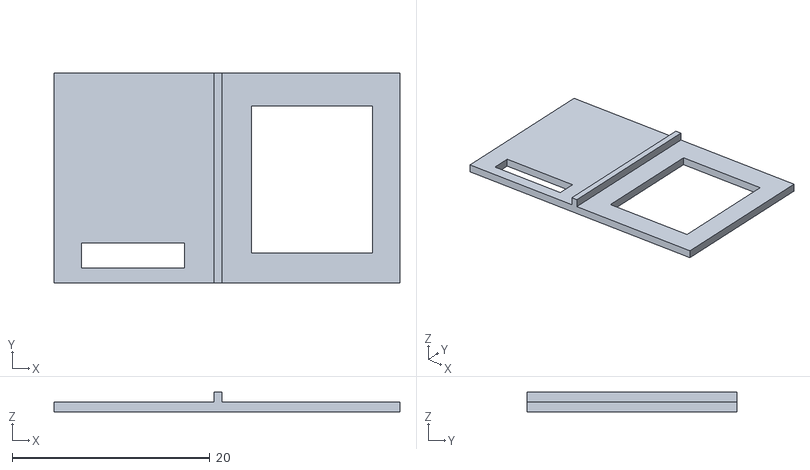
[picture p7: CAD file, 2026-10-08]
hardware/caixa/stl/air_mouse_bandeja.stl
35.0 x 21.2 x 2.00

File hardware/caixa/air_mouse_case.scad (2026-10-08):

// Air Mouse — caixa do chaveiro (formato B) para Seeed XIAO ESP32-C6
// Unidades: mm. Abra no OpenSCAD (gratuito), escolha a "peca" no Customizer,
// renderize (F6) e exporte o STL (F7). Imprima base, tampa e bandeja separadas.
//
// Eixos: X = largura (esquerda -> direita), Y = comprimento (frente -> tras),
// Z = altura. A origem e o canto interno frente-esquerda, em cima do fundo.
// A frente tem o laser e o LED IR; a traseira tem o USB-C da XIAO e o rasgo
// da argola do chaveiro (canto traseiro de baixo, a direita).

/* [Peca] */
peca = "montagem"; // [montagem, explodida, base, tampa, bandeja]

/* [Bateria com o TP4056 colado - MEDIR E AJUSTAR] */
bat_larg = 30;    // largura da bateria (X)
bat_comp = 30;    // comprimento da bateria (Y), da ponta da protecao ate o lado do USB
bat_esp  = 5.0;   // espessura da bateria (sem o TP4056)
tp_larg  = 17.5;  // largura da placa TP4056
tp_comp  = 28;    // comprimento da placa TP4056
tp_recuo = 0;     // quanto o USB do TP4056 fica para dentro da borda da bateria
abrir_usb_tp4056 = false; // abre um 2o furo USB-C para carregar pelo TP4056

/* [Placas] */
xiao_larg = 17.8;
xiao_comp = 21;
xiao_pcb  = 1.2;
mpu_larg  = 16.0; // GY-521, sem os pinos
mpu_comp  = 21.0;

/* [Acabamento] */
argola  = true;   // passagem escondida para argola de chaveiro
estrias = true;   // estrias laterais para a mao nao escorregar

/* [Caixa] */
parede  = 2.5;    // mais grossa para aguentar os cantos bem arredondados
fundo   = 2.0;
t_tampa = 2.0;
r_canto = 4;      // raio de TODAS as quinas (deixa a caixa "fofinha")
folga   = 0.15;   // folga da aba da tampa
explodir = 12;    // afastamento entre camadas na vista explodida

$fn = 48;

// ---------- medidas derivadas ----------
z_bat     = bat_esp + 0.5;          // topo da bateria (0,5 mm para ela poder estufar)
z_tp_topo = z_bat + 1.6 + 3.2;      // topo do conector USB do TP4056
z_bandeja = z_tp_topo + 0.7;        // fundo da bandeja das placas
z_placas  = z_bandeja + 1.0;        // XIAO e MPU apoiam aqui
int_h     = z_placas + 8.5;         // altura interna (ate a tampa)

pocket_mpu  = mpu_larg + 0.4;
pocket_xiao = xiao_larg + 0.4;
x_aba  = pocket_mpu;                // divisoria entre MPU e XIAO
x_xiao = x_aba + 0.8;
comp_placas = max(mpu_comp, xiao_comp) + 0.4;

int_w = max(pocket_mpu + 0.8 + pocket_xiao, bat_larg + 5.4);
int_l = max(bat_comp + 2.0, comp_placas + 10.6);
y_bandeja = int_l - comp_placas;

ext_w = int_w + 2 * parede;
ext_l = int_l + 2 * parede;
ext_h = fundo + int_h + t_tampa;

bat_y1 = int_l - 0.2;
bat_y0 = bat_y1 - bat_comp;
tp_y1  = bat_y1 - tp_recuo;
tp_y0  = tp_y1 - tp_comp;
tp_usb_x = tp_larg / 2;
tp_usb_z = z_bat + 1.6 + 1.6;

// laser (6 mm) e LED IR (3 mm) deitados na faixa livre da bateria, ao lado do TP4056,
// na mesma altura e com 1,2 mm de parede entre os dois furos
laser_x = tp_larg + 4;
laser_z = z_bat + 3;
ledir_d = 3;
ledir_x = laser_x + 6.1;
ledir_z = laser_z;

xiao_usb_x = x_xiao + pocket_xiao / 2;
xiao_usb_z = z_placas + xiao_pcb + 1.6;

cx = int_w / 2;
// 1 = liga/laser, 2 = clique, 3 = centro/velocidade, 4 = projetor
botoes = [[cx, 4.2], [cx, 14], [cx - 9.5, 21.5], [cx + 9.5, 21.5]];
rec_x = 6;   rec_y = 5;     // receptor IR deitado, lente para cima
led_x = int_w - 5.4; led_y = 6;  // LED RGB 3 mm

// passagem da argola: um rasgo estreito no canto traseiro de baixo (lado direito),
// aberto para tras e para baixo, com uma barrinha escondida dentro onde a argola
// abraca. Por dentro, um bolsinho fechado separa a argola da eletronica.
// Medido para argolas de ate 30 mm com arame de 2 mm.
bolso_x0  = int_w - 5.0;
rasgo_x0  = int_w - 4.2;
rasgo_larg = 3.4;
rasgo_comp = 7.5;   // quanto o rasgo avanca por baixo, a partir da parede de tras
rasgo_alt  = 6.0;   // altura do rasgo na traseira, a partir do fundo
barra_d    = 3.5;
barra_y    = int_l - 0.4;
barra_z    = 0.4;

assert(bat_larg - tp_larg >= 12, "A faixa livre ao lado do TP4056 precisa de 12 mm para o laser e o LED IR");
assert(y_bandeja >= 10.5, "Falta espaco na frente para o laser (10,5 mm)");
assert(!argola || bolso_x0 >= bat_larg + 0.3, "Sem espaco ao lado da bateria para a passagem da argola");

// ---------- utilitarios ----------
module casca() {
    // caixa inteira com todas as quinas arredondadas; base e tampa sao cortadas dela
    translate([-parede, -parede, -fundo]) hull()
        for (x = [r_canto, ext_w - r_canto], y = [r_canto, ext_l - r_canto], z = [r_canto, ext_h - r_canto])
            translate([x, y, z]) sphere(r = r_canto);
}
module cil_y(x, y, z, d, h) {
    translate([x, y, z]) rotate([-90, 0, 0]) cylinder(d = d, h = h);
}
module rasgo_y(w, h, comp) {
    hull() for (dx = [-(w - h) / 2, (w - h) / 2]) translate([dx, 0, 0]) cylinder(d = h, h = comp);
}
module furo_usb(x, z) {
    translate([x, int_l - 1, z]) rotate([-90, 0, 0]) rasgo_y(9.4, 3.6, parede + 2);
    // rebaixo externo para a capa do cabo chegar perto do conector (sobram 0,6 mm de parede)
    translate([x, int_l + 0.6, z]) rotate([-90, 0, 0]) rasgo_y(12.6, 7.0, parede + 1);
}

// ---------- base ----------
module ressaltos() {
    // apoios da bandeja nas paredes laterais, com chanfro de 45 graus (imprime sem suporte)
    hull() {
        translate([0, y_bandeja, z_bandeja - 1]) cube([1.2, int_l - y_bandeja, 1]);
        translate([0, y_bandeja, z_bandeja - 2.2]) cube([0.01, int_l - y_bandeja, 0.01]);
    }
    hull() {
        translate([int_w - 1.2, y_bandeja, z_bandeja - 1]) cube([1.2, int_l - y_bandeja, 1]);
        translate([int_w - 0.01, y_bandeja, z_bandeja - 2.2]) cube([0.01, int_l - y_bandeja, 0.01]);
    }
}
module estrias_cortes() {
    for (zz = [3 : 2.5 : 15.5]) {
        translate([-parede - 1, 3, zz - 0.5]) cube([1.5, int_l - 6, 1]);
        translate([int_w + parede - 0.5, 3, zz - 0.5]) cube([1.5, int_l - 6, 1]);
    }
}
module argola_rasgo() {
    translate([rasgo_x0, int_l - rasgo_comp, -fundo - 1])
        cube([rasgo_larg, rasgo_comp + parede + 1, fundo + 1 + rasgo_alt]);
}
module bolso_argola() {
    y0 = int_l - rasgo_comp - 0.8;
    h  = rasgo_alt + 0.8;
    translate([bolso_x0, y0, 0])            cube([5.0, 0.8, h]);                  // parede da frente
    translate([bolso_x0, y0, 0])            cube([0.8, int_l - y0, h]);           // parede do lado da bateria
    translate([int_w - 0.8, y0, 0])         cube([0.8, int_l - y0, h]);           // parede do lado de fora
    translate([bolso_x0, y0, rasgo_alt])    cube([5.0, int_l - y0, 0.8]);         // teto
    // barrinha onde a argola abraca (imprime como ponte, sem suporte)
    translate([rasgo_x0 - 0.01, barra_y, barra_z]) rotate([0, 90, 0]) cylinder(d = barra_d, h = rasgo_larg + 0.02);
}
module base() {
    difference() {
        intersection() {
            casca();
            translate([-50, -50, -50]) cube([200, 200, 50 + int_h]);
        }
        cube([int_w, int_l, int_h + 1]);
        cil_y(laser_x, -parede - 1, laser_z, 6.4, parede + 2);   // laser
        cil_y(ledir_x, -parede - 1, ledir_z, ledir_d + 0.3, parede + 2);   // LED IR
        furo_usb(xiao_usb_x, xiao_usb_z);
        if (abrir_usb_tp4056) furo_usb(tp_usb_x, tp_usb_z);
        if (estrias) estrias_cortes();
        if (argola) argola_rasgo();
    }
    ressaltos();
    if (argola) bolso_argola();
}

// ---------- bandeja (segura XIAO e MPU firmes) ----------
module bandeja() {
    difference() {
        union() {
            translate([0.2, y_bandeja, z_bandeja]) cube([int_w - 0.4, int_l - y_bandeja - 0.2, 1.0]);
            translate([x_aba, y_bandeja, z_placas]) cube([0.8, int_l - y_bandeja - 0.2, 1.0]);
        }
        // janela sob a XIAO para os fios dos pads de baixo (BAT+, BAT-, GPIO4-7)
        translate([x_xiao + 3, y_bandeja + 3, z_bandeja - 1]) cube([pocket_xiao - 6, comp_placas - 6.5, 3]);
        // passagem de fios ao lado do MPU (o resto fica inteiro para colar o MPU)
        translate([3, y_bandeja + 1.5, z_bandeja - 1]) cube([pocket_mpu - 6, 2.5, 3]);
    }
}
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

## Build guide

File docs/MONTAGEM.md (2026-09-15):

# Ordem de montagem e testes

Monte por etapas e teste cada uma antes de seguir. É muito mais fácil achar um
fio errado quando só existem três fios.

---

## Etapa 1 — Só a placa

Ligue o ESP32-C3 no USB, grave o firmware e abra o monitor serial.

```bash
pio run --target upload && pio device monitor
```

Esperado: a mensagem `MPU6050 nao respondeu` (normal, o sensor ainda não está
ligado) seguida de `Anunciando como "Air Mouse"`. O LED RGB pisca em vermelho, rápido.

Se não aparecer nada no monitor: confira se `USB CDC On Boot` está habilitado.

---

## Etapa 2 — MPU6050

Ligue os quatro fios: VCC→3V3, GND→GND, SDA→GPIO 5, SCL→GPIO 6.

Esperado no monitor:

```
Calibrando o giroscopio, mantenha o aparelho parado...
Calibrado. Bias: -1.23 / 0.45 / 2.10 deg/s
```

Deixe a placa **imóvel na mesa** durante essa parte.

**Se der `MPU6050 nao respondeu`:**

- SDA e SCL invertidos é o erro mais comum — tente trocar.
- Alguns módulos GY-521 vêm com o pino AD0 solto; ligue AD0 no GND para forçar o
  endereço 0x68.
- Confira se o módulo está em 3V3, não em 5V.
- Use o scanner I²C em [../tools/i2c_scanner](../tools/i2c_scanner) para ver se
  o sensor aparece em algum endereço.

**Se o bias sair muito alto (acima de ~10 dps em algum eixo):** você mexeu
durante a calibração. Reinicie.

---

## Etapa 3 — Bluetooth

Ainda pelo USB, pareie com o computador: *Bluetooth → Adicionar dispositivo →
Air Mouse*.

Assim que conectar, o LED apaga e o cursor já deve responder ao movimento da
placa.

É aqui que você ajusta `INVERT_X`, `INVERT_Y`, `SWAP_AXES` e `SENSITIVITY` em
[`include/config.h`](../include/config.h) — ver [AJUSTES.md](AJUSTES.md). Faça
isso agora, com tudo ainda na bancada: depois de soldar dentro da caixa fica bem
menos divertido.

---

## Etapa 4 — Botões

Cada botão: um lado no GPIO, o outro no GND. Não precisa de resistor.

- GPIO 3 → clique esquerdo
- GPIO 4 → clique direito
- GPIO 10 → segure para rolar a página
- GPIO 7 → centralizar o cursor
- GPIO 9 → trocar a velocidade

Teste os cinco antes de soldar definitivo.

O botão de centralizar precisa que `SCREEN_WIDTH` e `SCREEN_HEIGHT` batam com a
sua tela. Clique e veja onde o cursor para: se ficar sistematicamente longe do
centro, aumente `RECENTER_STEPS`.

**GPIO 9 é o pino BOOT.** Se esse botão estiver pressionado durante o reset, a
placa entra em modo de gravação em vez de arrancar. É inofensivo — e útil na hora
de gravar o firmware.

---

## Etapa 5 — LED RGB

Ânodo comum no **3V3**; cada cátodo vai ao GPIO por um resistor de **220 Ω**.

- GPIO 8 → vermelho
- GPIO 20 → verde
- GPIO 21 → azul

Ao ligar, o LED deve ficar azul fixo e depois piscar em azul devagar. Aperte o
botão de velocidade: a cor deve mudar para verde, amarelo ou vermelho por 1,5 s
e depois apagar.

Se as cores saírem trocadas, confira a ordem dos pinos. Se o LED ficar aceso ao
contrário — apagado quando deveria acender — você tem um LED de cátodo comum:
defina `RGB_COMMON_ANODE 0`. Nesse caso reveja o boot, porque GPIO 8 é pino de
strapping e passa a ficar em nível baixo em repouso.

---

## Etapa 6 — Baterias

**Faça esta etapa com o USB desconectado.**

### Antes de unir as células

Duas 18650 em paralelo com tensões diferentes trocam corrente entre si, e uma
diferença de 0,5 V pode gerar dezenas de ampères no instante da conexão.

1. Carregue cada célula **separadamente** até a mesma tensão.
2. Meça as duas com multímetro. A diferença precisa estar **abaixo de 0,05 V**.
3. Só então una os positivos entre si e os negativos entre si.

### Ligação

1. Positivos unidos → **B+** do TP4056. Negativos unidos → **B−**.
2. **OUT+** → um terminal da chave; outro terminal da chave → pino **5V** do ESP32.
3. **OUT−** → **GND** do ESP32.
4. Ligue a chave. A placa deve ligar e o LED começar a piscar em azul.

Confira com multímetro antes de ligar a chave pela primeira vez: entre OUT+ e
OUT− você deve ler algo entre 3,4 V e 4,2 V.

Uma célula só usa exatamente a mesma ligação — é só omitir a segunda.

### Carregando

Plugue o USB **no TP4056**, não no ESP32. LED vermelho = carregando, azul (ou
verde, depende do módulo) = cheio.

Com 6800 mAh, a carga completa leva de 12 a 15 horas — o TP4056 é linear e entra
em limitação térmica antes de sustentar 1 A. Ele **conclui** a carga, porque
encerra por corrente e não por tempo; só demora. Ver
[HARDWARE.md](HARDWARE.md#o-calor-que-é-o-limite-de-verdade).

O módulo fica quente durante horas. Não carregue com ele enfiado na caixa
fechada, e prefira a chave desligada durante a carga.

---

## Etapa 7 — Divisor de bateria (opcional)

```
  BAT+ (ou OUT+) ──[100k]──┬──[100k]── GND
                           │
                           ├── GPIO 1
                           │
                        [100nF] ── GND
```

Ligue no lado **OUT+** para que a leitura acompanhe o que a proteção está
entregando.

Depois de montar, coloque `#define DEBUG_PLOT_MS 500` e confira no monitor se a
porcentagem faz sentido. Bateria cheia deve mostrar perto de 100%.

Se o valor sair pela metade ou dobrado, ajuste `BAT_DIVIDER_RATIO` — ele é
`(R1+R2)/R2`. Com dois resistores iguais, é 2.0.

---

## Etapa 8 — Caixa

Ponto que faz diferença: **o MPU6050 precisa estar bem preso**. Se ele balançar
dentro da caixa, o cursor treme e nenhuma quantidade de filtro resolve. Cola
quente nas bordas do módulo já basta.

Oriente o módulo com o texto para cima e o lado dos pinos apontando para o lado
que você vai segurar. Se ficar em outra orientação, é só ajustar `SWAP_AXES` e
os `INVERT_*`.

Deixe o conector USB do TP4056 acessível por uma abertura na caixa.

---

## Checklist final

- [ ] Calibração no boot com o mouse parado
- [ ] Cursor anda no sentido certo nos dois eixos
- [ ] Os cinco botões respondem
- [ ] Centralizar leva o cursor para perto do meio da tela
- [ ] As três cores de velocidade aparecem e apagam sozinhas
- [ ] Reconecta sozinho ao ligar (bonding)
- [ ] Fica ocioso após 4 s e dorme após 20 min
- [ ] Acorda ao mover o aparelho, sem apertar nada
- [ ] Células equalizadas antes de unir em paralelo
- [ ] Carrega pelo TP4056 e a chave corta a alimentação
- [ ] MPU6050 firme na caixa
- [ ] LED de alimentação da placa removido

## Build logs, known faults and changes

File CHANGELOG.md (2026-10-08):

# Histórico

Formato baseado em [Keep a Changelog](https://keepachangelog.com/pt-BR/1.1.0/).

---

## Não lançado

Todo o conteúdo abaixo foi escrito, revisado e documentado, mas **nada foi
compilado nem executado em hardware**. Não há versão lançada porque não há nada
validado. Ver [Estado de verificação](README.md#estado-do-projeto).

### Firmware — base

- Driver do MPU6050 por acesso direto aos registradores I²C, sem biblioteca
  externa. Escala de ±500 °/s, DLPF de 44 Hz, taxa interna de 200 Hz.
- Calibração de bias no boot **com validação**: a medição é rejeitada quando a
  dispersão indica que a placa foi movida, caso em que o bias obtido faria o
  cursor derivar sozinho. Até três tentativas.
- Perfil HID de mouse implementado direto sobre o NimBLE, sem biblioteca HID de
  terceiros. As bibliotecas mais conhecidas dependem de Bluetooth Classic, que o
  ESP32-C3 não possui.
- Descritor com X e Y em **16 bits** em vez dos 8 bits habituais: em 8 bits o
  deslocamento satura em 127 por relatório e movimentos rápidos ficam truncados.
- Bonding habilitado — o host reconecta sozinho após o primeiro pareamento.

### Firmware — tratamento de sinal

Pipeline em `pointer.cpp`, nesta ordem (o porquê de cada etapa está em
[ARQUITETURA.md](docs/ARQUITETURA.md)):

- **Compensação de rotação do pulso** por filtro complementar. Sem ela, segurar o
  aparelho inclinado faz o cursor andar na diagonal.
- **Zona morta subtrativa** em vez de zerada, evitando o degrau de velocidade ao
  cruzar a borda do limiar.
- **Suavização exponencial**.
- **Curva de aceleração** com termo linear e quadrático.
- **Acumulador de sub-pixel**: a fração de pixel é preservada entre relatórios.
  Sem isso, todo movimento lento seria truncado a zero.

### Firmware — controles

- Modo scroll com o botão do meio segurado.
- **Botão de centralizar o cursor.** O HID reporta deslocamento relativo, nunca
  posição absoluta; a sequência encosta o cursor no canto superior esquerdo, onde
  o sistema o prende, e de lá caminha meia tela em passos pequenos. A chegada é
  próxima do centro, não exata — a aceleração de ponteiro do sistema distorce a
  segunda metade.
- **Três níveis de velocidade** (0,55× / 1,0× / 1,6×), percorridos por botão. O
  multiplicador incide sobre `SENSITIVITY` e `ACCEL_GAIN` juntos, preservando o
  formato da curva. O nível sobrevive ao sono profundo via RAM do RTC.
- **LED RGB** acumulando estado do aparelho e confirmação de velocidade. Ânodo
  comum, para manter GPIO 8 seguro como pino de strapping.

### Firmware — energia

Três estados: ativo (~22 mA), ocioso com conexão mantida (~1,9 mA, sai em ~50 ms)
e sono profundo (~84 µA, sai em 1 a 2 s). Estimativas de folha de dados, não
medições; composição peça por peça no [README](README.md#autonomia).

- **Slave latency** alternando entre 0 (ativo) e 40 (ocioso). O rádio deixa de
  acordar a cada 7,5 ms sem perder a capacidade de responder no evento seguinte.
  É o maior ganho isolado do projeto com a conexão ativa.
- Giroscópio posto em espera no estado ocioso; o acelerômetro assume a detecção
  de movimento a ~20 µA, contra 3,9 mA do modo pleno.
- **Despertar por movimento**: pegar o aparelho o acorda, sem apertar nada.
- CPU fixada em 80 MHz, mínimo com o rádio BLE estável no ESP32-C3.
- Light sleep automático entre quadros, com detecção de ausência de suporte a
  power management no core.
- Potência de transmissão reduzida de +9 para 0 dBm.
- Anúncio passa a intervalo lento após 30 s e dorme após 3 min sem conexão.
- Sono profundo adiado para 20 min, para que uma pausa durante uma aula não custe
  reconexão no momento em que se aponta para a tela.

### Estrutura

- Firmware separado em oito módulos com responsabilidade única; `main.cpp` cuida
  apenas de orquestração.
- Configuração inteira concentrada em [`include/config.h`](include/config.h).
- Versões fixadas no `platformio.ini`: arduino-esp32 2.0.17 via espressif32 6.9.0
  e NimBLE-Arduino 1.4.3.
- Scanner I²C em [`tools/i2c_scanner`](tools/i2c_scanner) para diagnóstico.

### Documentação

- [HARDWARE.md](docs/HARDWARE.md) — materiais, pinagem, alimentação, carga, peso.
- [MONTAGEM.md](docs/MONTAGEM.md) — montagem em oito etapas, com teste a cada uma.
- [ARQUITETURA.md](docs/ARQUITETURA.md) — como o firmware funciona e por quê.
- [AJUSTES.md](docs/AJUSTES.md) — sensibilidade, velocidade e diagnóstico.
- [ENERGIA.md](docs/ENERGIA.md) — orçamento de consumo e autonomia.

### Versão chaveiro (XIAO ESP32-C6) — em projeto

- [CHAVEIRO_C6.md](docs/CHAVEIRO_C6.md): versão compacta para sala de aula, com
  laser e um botão que grava e reenvia o código infravermelho do projetor. Traz a
  lista de compras, a pinagem da XIAO ESP32-C6, o mapa de botões e os estados de
  energia (desligado só acorda pelo botão, para não ligar sozinho na bolsa).
- [hardware/caixa](hardware/caixa/README.md): caixa paramétrica em OpenSCAD de
  40,4 × 37 × 24,5 mm, com quinas arredondadas, estrias laterais, bandeja que
  prende o MPU6050 e passagem escondida para a argola do chaveiro. STL das três
  peças incluídos; nenhuma foi impressa.
- O firmware para o C6 ainda não foi escrito.

---

## Decisões de projeto que valem registro

**HID direto sobre o NimBLE.** O ESP32-C3 só tem BLE. As bibliotecas de mouse
mais citadas dependem de Bluetooth Classic e não funcionam nesta peça; as
alternativas em BLE encapsulam o NimBLE e quebram a cada atualização do core.
Como o NimBLE já traz `NimBLEHIDDevice`, a camada extra só adicionaria
superfície de falha.

**O LED não fica aceso mostrando a velocidade.** Um LED aceso consome de 2 a 5 mA,
mais que o aparelho inteiro em repouso, e anularia boa parte da gestão de energia.
A cor aparece por 1,5 s na troca e ao conectar, que são os momentos em que a
informação serve.

**Divisor de bateria não chaveado.** Chegou a ser implementado, mas o GPIO que o
fazia virou o botão de centralizar quando os controles novos esgotaram os pinos.
Os 20 µA drenados são 0,3% de uma 18650 em um ano.

**Duas 18650 em paralelo.** Escolha consciente de autonomia sobre peso, para a
etapa de protótipo. O conjunto fica em ~160 g contra ~102 g com uma célula, e a
análise de peso está em
[HARDWARE.md](docs/HARDWARE.md#o-peso--vale-conversar-antes-de-comprar).

---

## Limites conhecidos

- **Nada foi compilado.** É o próximo passo.
- A sequência de registradores de wake-on-motion do MPU6050 foi escrita a partir
  da documentação e não foi verificada em hardware. É a parte com maior chance de
  precisar de ajuste.
- Os números de consumo são estimativas de folha de dados. Ver
  [ENERGIA.md](docs/ENERGIA.md#medindo-de-verdade).
- A centralização do cursor chega perto do centro, não no centro exato.
- Não há posicionamento absoluto, e não pode haver com HID relativo. Um formato
  que exija "apontar para onde o cursor deve ir" precisaria de referência externa.

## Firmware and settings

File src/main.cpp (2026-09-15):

#include <Arduino.h>
#include <Wire.h>
#include <math.h>

#include "battery.h"
#include "ble_mouse.h"
#include "button.h"
#include "config.h"
#include "mpu6050.h"
#include "pointer.h"
#include "power.h"
#include "recenter.h"
#include "rgb_led.h"

namespace {

// ATIVO: giroscopio a taxa cheia, cadencia de REPORT_HZ_ACTIVE e slave latency
// zero. OCIOSO: giroscopio em espera, sensor so no acelerometro a 5 Hz, slave
// latency alta e conexao mantida; sair custa ~50 ms. O sono profundo e tratado
// por Power::deepSleep().
enum class Mode { kActive, kIdle };

Button g_left(PIN_BTN_LEFT);
Button g_right(PIN_BTN_RIGHT);
Button g_middle(PIN_BTN_MID);
Button g_center(PIN_BTN_CENTER);
Button g_speed(PIN_BTN_SPEED);

// Sobrevive ao sono profundo, que apaga a RAM comum mas preserva a do RTC.
// Assim o nivel de velocidade escolhido continua valendo ao acordar.
RTC_DATA_ATTR uint8_t g_savedSpeed = SPEED_DEFAULT;

Mode     g_mode = Mode::kActive;
bool     g_sensorReady = false;
bool     g_advSlowed = false;
bool     g_wasConnected = false;
bool     g_centerWasPressed = false;
bool     g_speedWasPressed = false;
uint32_t g_lastFrameUs = 0;
uint32_t g_lastActivityMs = 0;
uint32_t g_lastBatteryMs = 0;
uint8_t  g_lastButtons = 0;

#if DEBUG_SERIAL
#define LOG(...) Serial.printf(__VA_ARGS__)
#else
#define LOG(...) ((void)0)
#endif

RgbLed::Color speedColor(Pointer::Speed speed) {
  switch (speed) {
    case Pointer::Speed::kFast: return RgbLed::Color::kGreen;
    case Pointer::Speed::kSlow: return RgbLed::Color::kRed;
    default:                    return RgbLed::Color::kYellow;
  }
}

const char *speedName(Pointer::Speed speed) {
  switch (speed) {
    case Pointer::Speed::kFast: return "rapido (verde)";
    case Pointer::Speed::kSlow: return "lento (vermelho)";
    default:                    return "medio (amarelo)";
  }
}

bool anyButtonPressed() {
  return g_left.pressed() || g_right.pressed() || g_middle.pressed() ||
         g_center.pressed() || g_speed.pressed();
}

void startSensor() {
  Wire.begin(PIN_SDA, PIN_SCL, 400000);

  if (!Mpu6050::begin()) {
    g_sensorReady = false;
    RgbLed::setState(RgbLed::State::kSensorError);
    LOG("MPU6050 nao respondeu. Verifique SDA, SCL, 3V3 e GND.\n");
    return;
  }

  LOG("Calibrando o giroscopio, mantenha o aparelho parado...\n");

  bool calibrated = false;
  for (int attempt = 0; attempt < 3 && !calibrated; attempt++) {
    calibrated = Mpu6050::calibrate();
  }

#if DEBUG_SERIAL
  const GyroBias &bias = Mpu6050::bias();
  LOG(calibrated ? "Calibrado. Bias: %.2f / %.2f / %.2f deg/s\n"
                 : "Calibracao instavel. Bias: %.2f / %.2f / %.2f deg/s\n",
      bias.x, bias.y, bias.z);
#endif

  g_sensorReady = true;
}

void enterIdle() {
  if (g_mode == Mode::kIdle) return;
  g_mode = Mode::kIdle;

  BleMouse::setLowLatency(false);
  Pointer::reset();

#if WAKE_ON_MOTION_ENABLED
  // O giroscopio sozinho custa 3,9 mA, mais que o ESP32 ocioso. Em repouso ele
  // sai de cena e o acelerometro assume a deteccao de movimento.
  if (g_sensorReady) Mpu6050::enterMotionDetect(WAKE_ON_MOTION_THRESHOLD);
#endif

  LOG("Ocioso.\n");
}

void enterActive() {
  if (g_mode == Mode::kActive) return;
  g_mode = Mode::kActive;

#if WAKE_ON_MOTION_ENABLED
  if (g_sensorReady) Mpu6050::exitMotionDetect();
#endif

  Pointer::reset();
  BleMouse::setLowLatency(true);
  g_lastFrameUs = micros();

  LOG("Ativo.\n");
}

// Em repouso o giroscopio esta desligado, entao quem sinaliza movimento e o
// pino INT do sensor.
bool motionDetected() {
#if WAKE_ON_MOTION_ENABLED
  return digitalRead(PIN_MPU_INT) == LOW;
#else
  ImuSample sample;
  if (!Mpu6050::read(sample)) return false;
  return fabsf(sample.gy) > IDLE_MOTION_DPS || fabsf(sample.gz) > IDLE_MOTION_DPS;
#endif
}

// Borda de subida: age no instante do aperto, nao enquanto segurado.
bool justPressed(const Button &button, bool &previous) {
  const bool now = button.pressed();
  const bool edge = now && !previous;
  previous = now;
  return edge;
}

void cycleSpeed() {
  const Pointer::Speed next = Pointer::nextSpeed();
  Pointer::setSpeed(next);
  g_savedSpeed = static_cast<uint8_t>(next);
  RgbLed::flash(speedColor(next));
  LOG("Velocidade: %s\n", speedName(next));
}

void refreshBattery() {
  if (millis() - g_lastBatteryMs < BATTERY_UPDATE_MS) return;
  g_lastBatteryMs = millis();
  BleMouse::setBatteryLevel(Battery::percent());
}

// Cede a CPU ate o proximo quadro. Diferente de um laco de espera, isto deixa
// o FreeRTOS entrar em light sleep no intervalo.
void waitForNextFrame(uint32_t periodUs) {
  const uint32_t elapsedUs = micros() - g_lastFrameUs;
  if (elapsedUs >= periodUs) return;

  const uint32_t remainingMs = (periodUs - elapsedUs) / 1000;
  if (remainingMs > 0) delay(remainingMs);
}

}  // namespace

void setup() {
#if DEBUG_SERIAL
  Serial.begin(115200);
  delay(300);
#endif

  Power::begin();

  RgbLed::begin();
  RgbLed::setState(RgbLed::State::kBooting);
  RgbLed::update();

  g_left.begin();
  g_right.begin();
  g_middle.begin();
  g_center.begin();
  g_speed.begin();

#if WAKE_ON_MOTION_ENABLED
  pinMode(PIN_MPU_INT, INPUT_PULLUP);
#endif

  Battery::begin();
  Pointer::reset();

  if (g_savedSpeed > 2) g_savedSpeed = SPEED_DEFAULT;
  Pointer::setSpeed(static_cast<Pointer::Speed>(g_savedSpeed));

  startSensor();

  BleMouse::begin(DEVICE_NAME, DEVICE_MANUFACTURER);

  if (g_sensorReady) RgbLed::setState(RgbLed::State::kAdvertising);

  g_mode = Mode::kActive;
  g_lastFrameUs = micros();
  g_lastActivityMs = millis();
  g_lastBatteryMs = millis();

  LOG("Anunciando como \"%s\". CPU %d MHz, light sleep %s, TX %d dBm.\n", DEVICE_NAME,
      CPU_FREQ_MHZ, Power::lightSleepActive() ? "ativo" : "indisponivel", BLE_TX_POWER_DBM);
  LOG("Velocidade: %s\n", speedName(Pointer::speed()));

  if (Power::wokeFromMotion()) LOG("Despertou por movimento.\n");
}

void loop() {
  RgbLed::update();

  g_left.update();
  g_right.update();
  g_middle.update();
  g_center.update();
  g_speed.update();

  const bool connected = BleMouse::connected();

  if (g_sensorReady) {
    RgbLed::setState(connected ? RgbLed::State::kConnected : RgbLed::State::kAdvertising);
  }

  // Ao conectar, mostra em que velocidade o aparelho esta - a escolha
  // sobreviveu ao sono profundo e o usuario pode nao lembrar dela.
  if (connected && !g_wasConnected) {
    RgbLed::flash(speedColor(Pointer::speed()));
  }
  g_wasConnected = connected;

  // Sem ninguem conectado, o anuncio rapido so vale durante a janela em que se
  // espera alguem procurando; depois dela o custo nao se paga.
  if (!connected) {
    if (!g_advSlowed && BleMouse::millisSinceConnected() > ADV_FAST_MS) {
      BleMouse::slowDownAdvertising();
      g_advSlowed = true;
      LOG("Anuncio lento.\n");
    }
    if (BleMouse::millisSinceConnected() > ADV_TIMEOUT_MS) {
      LOG("Ninguem conectou, dormindo.\n");
#if DEBUG_SERIAL
      Serial.flush();
#endif
      Power::deepSleep();
    }
  } else {
    g_advSlowed = false;
  }

  const uint32_t periodUs =
      1000000UL / (g_mode == Mode::kActive ? REPORT_HZ_ACTIVE : REPORT_HZ_IDLE);

  waitForNextFrame(periodUs);

  const uint32_t nowUs = micros();
  if (nowUs - g_lastFrameUs < periodUs) return;

  const float dt = (nowUs - g_lastFrameUs) / 1000000.0f;
  g_lastFrameUs = nowUs;

  // Os botoes de velocidade e centralizacao funcionam em qualquer estado.
  if (justPressed(g_speed, g_speedWasPressed)) {
    g_lastActivityMs = millis();
    cycleSpeed();
  }

  if (justPressed(g_center, g_centerWasPressed)) {
    g_lastActivityMs = millis();
    if (g_mode == Mode::kIdle) enterActive();
    Recenter::start();
    LOG("Centralizando.\n");
  }

  // Enquanto a sequencia roda, o giroscopio e ignorado: misturar o movimento
  // da mao com a caminhada ate o centro erraria o alvo.
  if (Recenter::running()) {
    if (!connected) {
      Recenter::cancel();
    } else {
      Recenter::update();
      return;
    }
  }

  if (!g_sensorReady) return;

  const uint8_t buttons =
      (g_left.pressed() ? BleMouse::kButtonLeft : 0) |
      (g_right.pressed() ? BleMouse::kButtonRight : 0);

  if (g_mode == Mode::kIdle) {
    if (motionDetected() || anyButtonPressed()) {
      g_lastActivityMs = millis();
      enterActive();
    } else {
      // Os botoes continuam sendo atendidos, so que na cadencia reduzida.
      if (buttons != g_lastButtons) {
        BleMouse::sendReport(buttons, 0, 0, 0, 0);
        g_lastButtons = buttons;
      }
      refreshBattery();
      if (millis() - g_lastActivityMs > IDLE_SLEEP_MS) {
        LOG("Inatividade prolongada, sono profundo.\n");
#if DEBUG_SERIAL
        Serial.flush();
#endif
        Power::deepSleep();
      }
    }
    return;
  }

  ImuSample sample;
  if (!Mpu6050::read(sample)) return;

  const PointerOutput motion = Pointer::update(sample, dt, g_middle.pressed());

  if (Pointer::speedDps() > IDLE_MOTION_DPS || anyButtonPressed()) {
    g_lastActivityMs = millis();
  }

  const bool hasMotion = motion.dx != 0 || motion.dy != 0 || motion.wheel != 0;
  if (hasMotion || buttons != g_lastButtons) {
    BleMouse::sendReport(buttons, motion.dx, motion.dy, motion.wheel, 0);
    g_lastButtons = buttons;
  }

#if DEBUG_PLOT_MS > 0
  static uint32_t lastPlotMs = 0;
  if (millis() - lastPlotMs > DEBUG_PLOT_MS) {
    lastPlotMs = millis();
    LOG("dx=%d dy=%d wheel=%d bateria=%.2fV (%u%%)\n", motion.dx, motion.dy, motion.wheel,
        Battery::volts(), Battery::percent());
  }
#endif

  refreshBattery();

  if (millis() - g_lastActivityMs > IDLE_ENTER_MS) {
    enterIdle();
  }
}

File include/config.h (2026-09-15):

#pragma once

// Ponto unico de configuracao do firmware. Ver docs/AJUSTES.md para o efeito
// pratico de cada parametro e docs/ENERGIA.md para o orcamento de consumo.

// ---------------------------------------------------------------------------
// Identificacao
// ---------------------------------------------------------------------------
#define DEVICE_NAME         "Air Mouse"
#define DEVICE_MANUFACTURER "IgorPFernandes"

// ---------------------------------------------------------------------------
// Pinos (ESP32-C3)
//
// A SuperMini expoe GPIO 0 a 10, 20 e 21: treze pinos, doze deles usados aqui.
// GPIO 2 e o unico que sobra, deixado livre de proposito por ser pino de
// strapping - se estiver em nivel baixo no reset, a placa nao arranca.
//
// GPIO 20 e 21 sao a UART0, livres porque a serial usa o USB nativo.
// GPIO 9 e o pino BOOT: segura-lo durante o reset entra em modo de gravacao,
// o que e inofensivo mas confunde quem nao espera.
//
// PIN_BTN_LEFT e PIN_MPU_INT precisam estar entre GPIO 0 e 5: e a unica faixa
// que acorda o ESP32-C3 do sono profundo. Verificado em power.cpp.
// ---------------------------------------------------------------------------
#define PIN_SDA         5
#define PIN_SCL         6

#define PIN_BTN_LEFT    3
#define PIN_BTN_RIGHT   4
#define PIN_BTN_MID    10
#define PIN_BTN_CENTER  7   // centraliza o cursor na tela
#define PIN_BTN_SPEED   9   // percorre lento -> medio -> rapido

#define PIN_MPU_INT     0   // INT do MPU6050, desperta por movimento
#define PIN_BAT_ADC     1

// LED RGB de anodo comum: cada catodo vai ao GPIO por um resistor de 220 ohm
// e o anodo comum ao 3V3. Anodo comum de proposito - os pinos ficam em nivel
// alto em repouso, o que mantem GPIO 8 seguro como pino de strapping.
#define PIN_RGB_R       8
#define PIN_RGB_G      20
#define PIN_RGB_B      21
#define RGB_COMMON_ANODE 1

// ---------------------------------------------------------------------------
// Bateria
// ---------------------------------------------------------------------------
#define BATTERY_SENSE_ENABLED 1

// (R1 + R2) / R2. Com dois resistores de 100 k, o valor e 2.0.
#define BAT_DIVIDER_RATIO 2.0f

// O pe do divisor ligado direto ao GND drena cerca de 20 uA continuos. Com uma
// celula pequena isso pesava; com 18650 em paralelo sao 0,3% da capacidade em
// um ano, e o GPIO que fazia o chaveamento vale mais como botao. Para voltar a
// chavear, defina 1 e escolha um pino livre para PIN_BAT_GND.
#define BATTERY_GATED 0

#define BATTERY_UPDATE_MS 120000UL

// ---------------------------------------------------------------------------
// Orientacao
// ---------------------------------------------------------------------------
#define SWAP_AXES         0
#define INVERT_X          1
#define INVERT_Y          1

// Mantem os eixos da tela corretos com o aparelho inclinado de lado.
#define ROLL_COMPENSATION 1

// ---------------------------------------------------------------------------
// Resposta do cursor
// ---------------------------------------------------------------------------
#define REPORT_HZ_ACTIVE  125
#define REPORT_HZ_IDLE    50       // cadencia enquanto nao ha movimento

#define GYRO_DEADZONE_DPS 1.2f     // abaixo disso e tremor de mao
#define SMOOTHING         0.35f    // 0 = sem filtro, 0.9 = bem lento
#define SENSITIVITY       0.085f   // ganho linear, px por deg/s
#define ACCEL_GAIN        0.0016f  // ganho quadratico
#define MAX_STEP          90       // teto de px por relatorio

#define SCROLL_DIVISOR    18.0f    // maior = scroll mais lento
#define SCROLL_INVERT     0

// ---------------------------------------------------------------------------
// Niveis de velocidade
//
// O botao de velocidade percorre os tres. O multiplicador incide sobre
// SENSITIVITY e ACCEL_GAIN ao mesmo tempo, para que a curva mantenha o mesmo
// formato e so mude de escala.
// ---------------------------------------------------------------------------
#define SPEED_SLOW_SCALE   0.55f   // vermelho
#define SPEED_MEDIUM_SCALE 1.00f   // amarelo, os valores acima como estao
#define SPEED_FAST_SCALE   1.60f   // verde

#define SPEED_DEFAULT 1            // 0 lento, 1 medio, 2 rapido

// ---------------------------------------------------------------------------
// Centralizacao do cursor
//
// O HID reporta deslocamento relativo, entao nao existe "ir para a posicao X".
// O firmware encosta o cursor no canto superior esquerdo, onde o sistema o
// prende, e de la caminha meia tela. Precisa saber o tamanho da tela.
// ---------------------------------------------------------------------------
#define SCREEN_WIDTH   1920
#define SCREEN_HEIGHT  1080

// Passos em que a caminhada ate o centro e dividida. Muitos passos pequenos
// sofrem menos com a aceleracao de ponteiro do sistema do que um salto unico.
#define RECENTER_STEPS 24
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

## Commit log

2026-09-01 chore: configura projeto PlatformIO para ESP32-C3
    Versoes fixadas (arduino-esp32 2.0.17 via espressif32 6.9.0 e NimBLE 1.4.3)
    por serem a combinacao estavel para BLE HID no ESP32-C3.
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2026-09-01 feat: adiciona driver do MPU6050
    Acesso I2C direto aos registradores, sem biblioteca externa. Escala de
    +-500 deg/s e DLPF de 44 Hz. A calibracao rejeita a medicao quando detecta
    que a placa foi movida, caso em que o bias obtido faria o cursor derivar.
2026-09-01 feat: adiciona mouse HID sobre BLE
    Implementa o perfil HID direto sobre o NimBLE. As bibliotecas HID mais
    conhecidas dependem de Bluetooth Classic, que o ESP32-C3 nao possui.
    Deslocamento em 16 bits em vez dos 8 bits habituais: em 8 bits o valor
    satura em 127 e movimentos rapidos ficam truncados.
2026-09-01 feat: adiciona pipeline de movimento do cursor
    Etapas, nesta ordem: compensacao de rotacao por filtro complementar,
    mapeamento de eixos, zona morta subtrativa, suavizacao exponencial, curva
    de aceleracao e acumulador de sub-pixel.
    A zona morta subtrai o limiar em vez de zerar, o que evita o degrau de
    velocidade ao cruzar a borda. O acumulador guarda a fracao de pixel entre
    relatorios, sem a qual todo movimento lento seria truncado para zero.
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2026-09-01 feat: adiciona medicao de bateria
    Le o divisor resistivo pelo ADC e converte por interpolacao na curva de
    descarga da celula LiPo. A leitura e a media de oito amostras porque o ADC
    do ESP32-C3 oscila varios pontos percentuais entre chamadas.
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2026-09-01 feat: adiciona sono profundo com despertar por botao
    O pino de despertar precisa estar entre GPIO 0 e 5, unica faixa que acorda
    o ESP32-C3 do sono profundo; a restricao e verificada em tempo de compilacao.
2026-09-01 feat: adiciona configuracao central e laco principal
    main.cpp cuida apenas da orquestracao: inicializa os modulos, mantem a
    cadencia fixa de 125 Hz e decide quando enviar relatorio ou dormir.
    Todo parametro ajustavel fica em include/config.h.
    [config.h, main.cpp]
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2026-09-01 docs: documenta arquitetura do firmware e ajuste do cursor
    Registra a ordem do pipeline de tratamento de sinal e a razao de cada
    etapa, que e a parte do projeto menos evidente pela leitura do codigo.
2026-09-15 feat: adiciona modo de deteccao de movimento ao MPU6050
    Coloca o giroscopio em espera e o acelerometro em ciclo de 5 Hz, com o pino
    INT sinalizando movimento acima do limiar. Reduz o consumo do sensor de
    3,9 mA para cerca de 20 uA, o que passa a permitir manter a deteccao ligada
    com o ESP32 dormindo.
    A sequencia de registradores de wake-on-motion ainda nao foi verificada em
    hardware.
2026-09-15 feat: gerencia parametros de conexao e potencia do radio
    Introduz slave latency alta em repouso: o radio deixa de acordar a cada
    evento de conexao quando nao ha nada a enviar, sem perder a capacidade de
    responder no evento seguinte quando ha. E o maior ganho de energia com a
    conexao ativa.
    Reduz a potencia de transmissao de +9 para 0 dBm, suficiente para uso em
    mesa, e passa o anuncio para intervalo lento depois da janela de busca.
2026-09-15 feat: reduz clock, habilita light sleep e desperta por movimento
    CPU fixada em 80 MHz, minimo com o radio BLE estavel no ESP32-C3 e cerca de
    metade da corrente dos 160 MHz padrao. Light sleep automatico via
    esp_pm_configure, com deteccao de ausencia de suporte no core.
    O sono profundo agora desperta tambem pelo pino INT do sensor, de modo que
    pegar o aparelho basta para acorda-lo.
    [power.cpp]
2026-09-15 fix: elimina drenagem continua do divisor de bateria
    O divisor de 100 k + 100 k ligado ao terra drena cerca de 20 uA sem parar,
    o que sozinho dominaria o consumo do aparelho dormindo. O pe do divisor
    passa a ser um GPIO em alta impedancia, levado a nivel baixo apenas durante
    a medicao.
    [battery.cpp]
2026-09-15 feat: adiciona maquina de estados de energia
    Tres estados: ativo, ocioso com conexao mantida e sono profundo. O estado
    ocioso poupa o giroscopio e o radio sem derrubar a conexao, custando ~50 ms
    para sair; o sono profundo custa uma reconexao.
    A espera entre quadros passa a ceder a CPU em vez de girar em laco, o que e
    o que permite ao FreeRTOS entrar em light sleep no intervalo.
2026-09-15 docs: documenta orcamento de energia e mudancas de ligacao
    Registra o consumo estimado de cada estado, o efeito do slave latency e as
    duas limitacoes de hardware que o firmware nao alcanca: o LED de
    alimentacao da placa e a corrente de repouso do regulador.
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2026-09-15 feat: substitui LED de status por LED RGB
    O RGB acumula as duas funcoes: estado do aparelho antes de conectar e
    confirmacao do nivel de velocidade depois. Anodo comum de proposito, para
    os pinos ficarem em nivel alto em repouso e GPIO 8 seguir seguro como pino
    de strapping.
    A cor aparece so por RGB_CONFIRM_MS apos uma troca ou apos conectar. Um LED
    aceso continuamente consome de 2 a 5 mA, mais que o aparelho inteiro em
    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
2026-09-15 docs: corrige estimativa de tempo de carga e explica o limite termico
    A estimativa anterior de 9 a 10 horas ignorava a limitacao termica: o TP4056
    e linear e dissipa cerca de 1,6 W a 1 A, o que o faz reduzir a corrente antes
    de sustentar o valor programado. O tempo real fica entre 12 e 15 horas.
    Registra tambem por que o pacote carrega por completo: o encerramento e por
    corrente e nao por tempo, e o corte em 100 mA absolutos representa C/68 num
    pacote de 6800 mAh, mais adiante na curva do que num pacote pequeno.
2026-09-15 feat: adia o sono profundo para 20 minutos
    Sair do sono profundo custa uma reconexao BLE de 1 a 2 s. Com o limite em
    2 min, uma pausa durante uma aula fazia o aparelho parecer sem resposta no
    momento em que o apresentador aponta para a tela.
    O estado ocioso custa 2 mA: uma jornada de 8 h sem dormir nenhuma vez gasta
    16 mAh, meio por cento de uma 18650. A latencia diante de uma turma custa
    mais que isso.
    Documenta o perfil de jornada de 8 h e corrige a nota do divisor de bateria,
    que deixou de ser chaveado quando o GPIO 7 virou botao.
    [config.h]
2026-09-15 docs: corrige a classe de comparacao do peso
    Comparar com mouse de mesa e enganoso: o mouse de mesa esta apoiado e a carga
    sustentada pela mao e praticamente zero. A referencia correta para uso em
    apresentacao e o apresentador de slides comercial, de 50 a 75 g.
    Acrescenta a distribuicao de massa, que para um aparelho operado por rotacao
    de pulso pesa mais que a massa total: duas celulas enfileiradas dobram o
    esforco de rotacao em relacao as mesmas celulas lado a lado.
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2026-09-15 docs: corrige o ciclo de trabalho do perfil de uso
    O modelo anterior supunha 10% do tempo em movimento, o que so valeria com o
    aparelho apoiado na mesa. Segurar o aparelho o mantem em estado ativo: o
    estado ocioso exige 4 s seguidos abaixo de 6 graus/s, e uma mao segurando um
    objeto nunca fica assim.
    Perfil de referencia passa a ser 8 h na mao e 16 h desligado na chave, o que
    leva o consumo de 33 para 176 mAh por jornada e a autonomia de 29 para 6,7
    semanas com duas 18650.
    Isso tambem inverte a ordem dos riscos. Com a chave desligada 16 h por dia, o
    LED de alimentacao e o regulador so drenam durante as 8 h de uso, onde os
    22 mA do estado ativo ja dominam; o fator critico passa a ser a proc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
2026-10-08 feat: adiciona a caixa imprimivel da versao chaveiro com XIAO ESP32-C6
    Versao compacta para sala de aula: air mouse com laser e um botao que
    grava o codigo infravermelho do controle do projetor e o reenvia, para o
    professor nao depender do controle da sala.
    A caixa e um modelo parametrico em OpenSCAD de 40,4 x 37 x 24,5 mm,
    montado em volta do bloco bateria + TP4056 que ja vem colado. O laser e o
    LED IR ficam na faixa livre ao lado do TP4056, e uma bandeja prende o
    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
    [air_mouse_bandeja.stl, air_mouse_base.stl, air_mouse_case.scad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]
2026-10-08 docs: escolhe os modelos de cada peca da versao chaveiro
    A lista de compras dizia o tipo de peca, mas nao qual comprar. Agora
    cada item tem o modelo, o termo de busca e o que conferir no anuncio,
    porque laser, receptor e botao variam muito entre vendedores.
    O receptor escolhido (TSOP38238) mede 6,95 mm e o soquete da tampa
    tinha 7,0 mm, folga apertada demais para impressao. O soquete passa a
    8,0 x 6,2 mm, o que tambem acomoda o VS1838B, a alternativa facil de
    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
    [air_mouse_case.scad, air_mouse_tampa.stl]
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2026-10-27 docs: adiciona esquematico da versao chaveiro e revisa as ligacoes
    ESQUEMATICO_C6.md traz o mapa de pinos da XIAO ESP32-C6, o circuito de
    cada componente em SVG e a lista de ligacoes por rede. A tabela do
    CHAVEIRO_C6.md diz qual pino vai onde, mas nao mostra resistores,
    transistores e capacitores no lugar; para montar e preciso o desenho.
    A revisao conferiu os pinos de despertar (todos nos GPIO 0-7), o ADC,
    os pinos de boot do C6 e os reservados da XIAO, as correntes por pino e
    o estado dos drivers no sono profundo. Ela corrigiu:
    - 100 nF no VS do receptor IR, que e alimentado por um pino e precisa
    da alimentacao filtrada para nao gravar codigo com ruido;
    - resistor de 22 ohms do LED IR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
